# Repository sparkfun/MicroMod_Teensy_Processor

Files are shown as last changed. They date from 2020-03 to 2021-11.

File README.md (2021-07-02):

SparkFun MicroMod Teensy Processor Board 
========================================

SparkFun MicroMod Teensy Processor Board

[SparkFun MicroMod Teensy Processor Board](https://www.sparkfun.com/products/16402)

The SparkFun MicroMod Teensy Processor Board leverages the incredible computing power of the NXP iMXRT1062 chip and pairs it with the M.2 MicroMod connector to allow you to plug it into your choice of compatible SparkFun MicroMod Carrier Board.

Repository Contents
-------------------

* **/Documents** - Datasheets, schematic, etc.
* **/Hardware** - Eagle design files (.brd, .sch)

Documentation
--------------
* **[Hookup Guide](https://learn.sparkfun.com/tutorials/micromod-teensy-processor-hookup-guide)** - Basic hookup guide for the SparkFun MicroMod Teensy Processor Board
* **[MicroMod Info Page](https://www.sparkfun.com/micromod)** - MicroMod Information Page

Version History
---------------
* **[DEV-16402](https://www.sparkfun.com/products/16402)** - Initial release.

License Information
-------------------

This product is _**open source**_! 

Please review the LICENSE.md file for license information. 

If you have any questions or concerns on licensing, please contact technical support on our [SparkFun forums](https://forum.sparkfun.com/viewforum.php?f=152).

Distributed as-is; no warranty is given.

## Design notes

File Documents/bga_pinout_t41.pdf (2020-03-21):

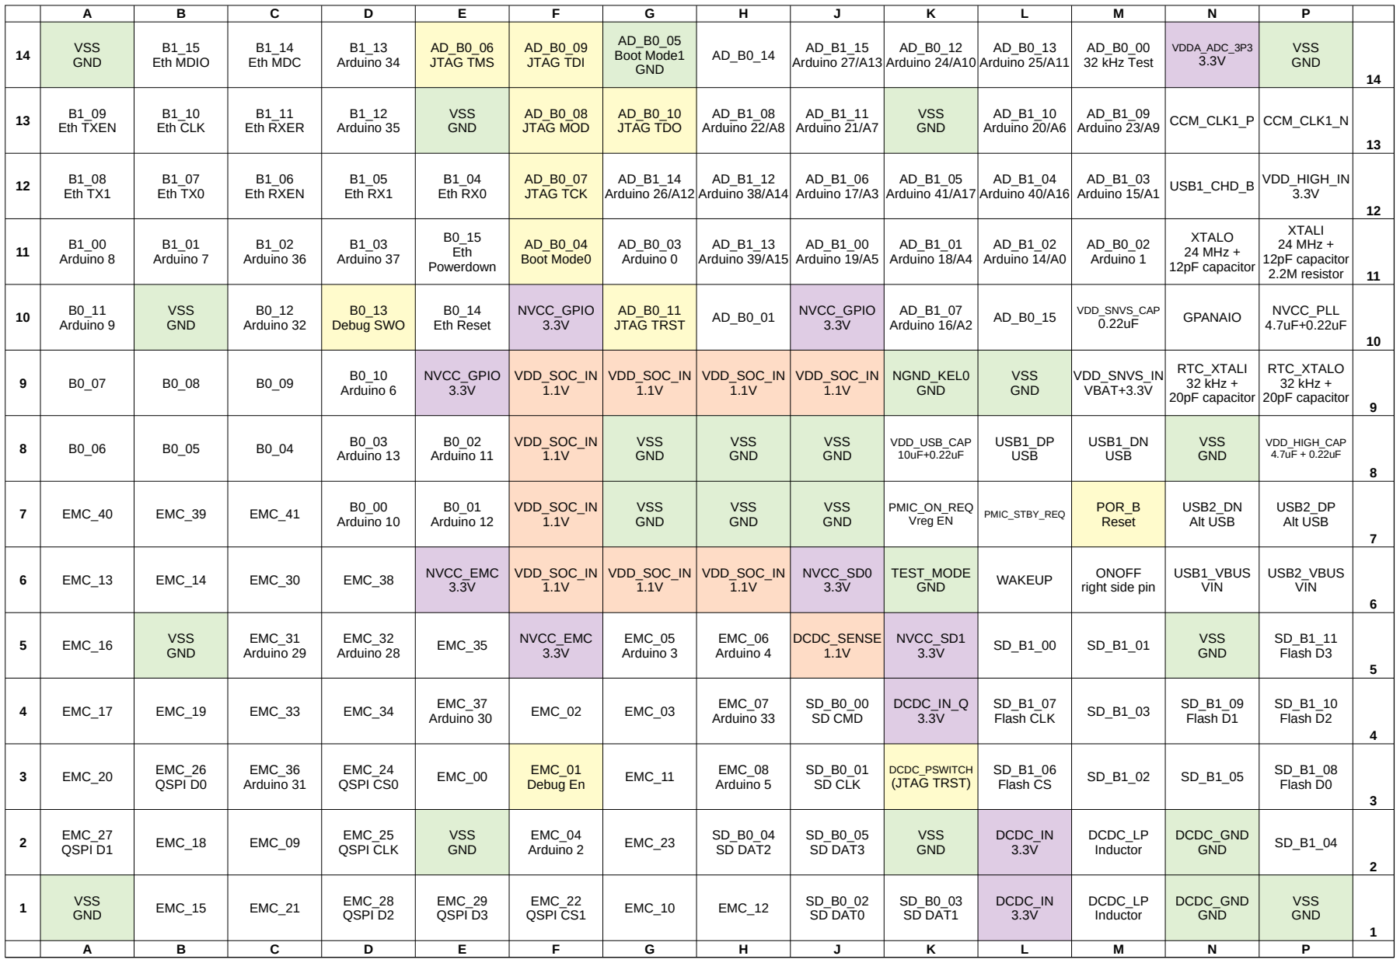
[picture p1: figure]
CCM_CLK1_P; CCM_CLK1_N; 12 USB1_CHD_B; GPANAIO; EMC_40; EMC_39; EMC_41; PMIC_STBY_REQ; EMC_13; EMC_14; EMC_30; EMC_38; WAKEUP; EMC_16; EMC_35; EMC_17; EMC_19; EMC_33; EMC_34; EMC_02; EMC_03; EMC_20; EMC_00; EMC_11; EMC_18; EMC_09; EMC_23; EMC_15; EMC_21; EMC_10; EMC_12; VSS GND; B1_15 Eth MDIO; B1_14 Eth MDC; B1_13 Arduino 34; AD_B0_06 JTAG TMS; AD_B0_09 JTAG TDI; AD_B0_05 Boot Mode1 GND; AD_B1_15 Arduino 27/A13; AD_B0_12 Arduino 24/A10; AD_B0_13 Arduino 25/A11; AD_B0_00 32 kHz Test; VDDA_ADC_3P3 3.3V; B1_09 Eth TXEN; B1_10 Eth CLK; B1_11 Eth RXER; B1_12 Arduino 35; AD_B0_08 JTAG MOD; AD_B0_10 JTAG TDO; AD_B1_08 Arduino 22/A8; AD_B1_11 Arduino 21/A7; AD_B1_10 Arduino 20/A6; AD_B1_09 Arduino 23/A9; B1_08 Eth TX1; B1_07 Eth TX0; B1_06 Eth RXEN; B1_05 Eth RX1; B1_04 Eth RX0; AD_B0_07 JTAG TCK; AD_B1_14 Arduino 26/A12; AD_B1_12 Arduino 38/A14; AD_B1_06 Arduino 17/A3; AD_B1_05 Arduino 41/A17; AD_B1_04 Arduino 40/A16; AD_B1_03 Arduino 15/A1; VDD_HIGH_IN 3.3V; B1_00 Arduino 8; B1_01 Arduino 7; B1_02 Arduino 36; B1_03 Arduino 37; B0_15 Eth Powerdown; AD_B0_04 Boot Mode0; AD_B0_03 Arduino 0; AD_B1_13 Arduino 39/A15; AD_B1_00 Arduino 19/A5; AD_B1_01 Arduino 18/A4; AD_B1_02 Arduino 14/A0; AD_B0_02 Arduino 1; XTALO 24 MHz + 12pF capacitor; XTALI 24 MHz + 12pF capacitor 2.2M resistor; B0_11 Arduino 9; B0_12 Arduino 32; B0_13 Debug SWO; B0_14 Eth Reset; NVCC_GPIO 3.3V; AD_B0_11 JTAG TRST; AD_B1_07 Arduino 16/A2; VDD_SNVS_CAP 0.22uF; NVCC_PLL 4.7uF+0.22uF; B0_10 Arduino 6; VDD_SOC_IN 1.1V; NGND_KEL0 GND; VDD_SNVS_IN VBAT+3.3V; RTC_XTALI 32 kHz + 20pF capacitor; RTC_XTALO 32 kHz + 20pF capacitor; B0_03 Arduino 13; B0_02 Arduino 11; VDD_USB_CAP 10uF+0.22uF; USB1_DP USB; USB1_DN USB; VDD_HIGH_CAP 4.7uF + 0.22uF; B0_00 Arduino 10; B0_01 Arduino 12; PMIC_ON_REQ Vreg EN; POR_B Reset; USB2_DN Alt USB; USB2_DP Alt USB; NVCC_EMC 3.3V; NVCC_SD0 3.3V; TEST_MODE GND; ONOFF right side pin; USB1_VBUS VIN; USB2_VBUS VIN; EMC_31 Arduino 29; EMC_32 Arduino 28; EMC_05 Arduino 3; EMC_06 Arduino 4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

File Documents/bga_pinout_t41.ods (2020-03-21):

 | A | B | C | D | E | F | G | H | J | K | L | M | N | P
14 | VSS GND | B1_15 Eth MDIO | B1_14 Eth MDC | B1_13 Arduino 34 | AD_B0_06 JTAG TMS | AD_B0_09 JTAG TDI | AD_B0_05 Boot Mode1 GND | AD_B0_14 | AD_B1_15 Arduino 27/A13 | AD_B0_12 Arduino 24/A10 | AD_B0_13 Arduino 25/A11 | AD_B0_00 32 kHz Test | VDDA_ADC_3P3 3.3V | VSS GND | 14
13 | B1_09 Eth TXEN | B1_10 Eth CLK | B1_11 Eth RXER | B1_12 Arduino 35 | VSS GND | AD_B0_08 JTAG MOD | AD_B0_10 JTAG TDO | AD_B1_08 Arduino 22/A8 | AD_B1_11 Arduino 21/A7 | VSS GND | AD_B1_10 Arduino 20/A6 | AD_B1_09 Arduino 23/A9 | CCM_CLK1_P | CCM_CLK1_N | 13
12 | B1_08 Eth TX1 | B1_07 Eth TX0 | B1_06 Eth RXEN | B1_05 Eth RX1 | B1_04 Eth RX0 | AD_B0_07 JTAG TCK | AD_B1_14 Arduino 26/A12 | AD_B1_12 Arduino 38/A14 | AD_B1_06 Arduino 17/A3 | AD_B1_05 Arduino 41/A17 | AD_B1_04 Arduino 40/A16 | AD_B1_03 Arduino 15/A1 | USB1_CHD_B | VDD_HIGH_IN 3.3V | 12
11 | B1_00 Arduino 8 | B1_01 Arduino 7 | B1_02 Arduino 36 | B1_03 Arduino 37 | B0_15 Eth Powerdown | AD_B0_04 Boot Mode0 | AD_B0_03 Arduino 0 | AD_B1_13 Arduino 39/A15 | AD_B1_00 Arduino 19/A5 | AD_B1_01 Arduino 18/A4 | AD_B1_02 Arduino 14/A0 | AD_B0_02 Arduino 1 | XTALO 24 MHz + 12pF capacitor | XTALI 24 MHz + 12pF capacitor 2.2M resistor | 11
10 | B0_11 Arduino 9 | VSS GND | B0_12 Arduino 32 | B0_13 Debug SWO | B0_14 Eth Reset | NVCC_GPIO 3.3V | AD_B0_11 JTAG TRST | AD_B0_01 | NVCC_GPIO 3.3V | AD_B1_07 Arduino 16/A2 | AD_B0_15 | VDD_SNVS_CAP 0.22uF | GPANAIO | NVCC_PLL 4.7uF+0.22uF | 10
9 | B0_07 | B0_08 | B0_09 | B0_10 Arduino 6 | NVCC_GPIO 3.3V | VDD_SOC_IN 1.1V | VDD_SOC_IN 1.1V | VDD_SOC_IN 1.1V | VDD_SOC_IN 1.1V | NGND_KEL0 GND | VSS GND | VDD_SNVS_IN VBAT+3.3V | RTC_XTALI 32 kHz + 20pF capacitor | RTC_XTALO 32 kHz + 20pF capacitor | 9
8 | B0_06 | B0_05 | B0_04 | B0_03 Arduino 13 | B0_02 Arduino 11 | VDD_SOC_IN 1.1V | VSS GND | VSS GND | VSS GND | VDD_USB_CAP 10uF+0.22uF | USB1_DP USB | USB1_DN USB | VSS GND | VDD_HIGH_CAP 4.7uF + 0.22uF | 8
7 | EMC_40 | EMC_39 | EMC_41 | B0_00 Arduino 10 | B0_01 Arduino 12 | VDD_SOC_IN 1.1V | VSS GND | VSS GND | VSS GND | PMIC_ON_REQ Vreg EN | PMIC_STBY_REQ | POR_B Reset | USB2_DN Alt USB | USB2_DP Alt USB | 7
6 | EMC_13 | EMC_14 | EMC_30 | EMC_38 | NVCC_EMC 3.3V | VDD_SOC_IN 1.1V | VDD_SOC_IN 1.1V | VDD_SOC_IN 1.1V | NVCC_SD0 3.3V | TEST_MODE GND | WAKEUP | ONOFF right side pin | USB1_VBUS VIN | USB2_VBUS VIN | 6
5 | EMC_16 | VSS GND | EMC_31 Arduino 29 | EMC_32 Arduino 28 | EMC_35 | NVCC_EMC 3.3V | EMC_05 Arduino 3 | EMC_06 Arduino 4 | DCDC_SENSE 1.1V | NVCC_SD1 3.3V | SD_B1_00 | SD_B1_01 | VSS GND | SD_B1_11 Flash D3 | 5
4 | EMC_17 | EMC_19 | EMC_33 | EMC_34 | EMC_37 Arduino 30 | EMC_02 | EMC_03 | EMC_07 Arduino 33 | SD_B0_00 SD CMD | DCDC_IN_Q 3.3V | SD_B1_07 Flash CLK | SD_B1_03 | SD_B1_09 Flash D1 | SD_B1_10 Flash D2 | 4
3 | EMC_20 | EMC_26 QSPI D0 | EMC_36 Arduino 31 | EMC_24 QSPI CS0 | EMC_00 | EMC_01 Debug En | EMC_11 | EMC_08 Arduino 5 | SD_B0_01 SD CLK | DCDC_PSWITCH (JTAG TRST) | SD_B1_06 Flash CS | SD_B1_02 | SD_B1_05 | SD_B1_08 Flash D0 | 3
2 | EMC_27 QSPI D1 | EMC_18 | EMC_09 | EMC_25 QSPI CLK | VSS GND | EMC_04 Arduino 2 | EMC_23 | SD_B0_04 SD DAT2 | SD_B0_05 SD DAT3 | VSS GND | DCDC_IN 3.3V | DCDC_LP Inductor | DCDC_GND GND | SD_B1_04 | 2
1 | VSS GND | EMC_15 | EMC_21 | EMC_28 QSPI D2 | EMC_29 QSPI D3 | EMC_22 QSPI CS1 | EMC_10 | EMC_12 | SD_B0_02 SD DAT0 | SD_B0_03 SD DAT1 | DCDC_IN 3.3V | DCDC_LP Inductor | DCDC_GND GND | VSS GND | 1
 | A | B | C | D | E | F | G | H | J | K | L | M | N | P

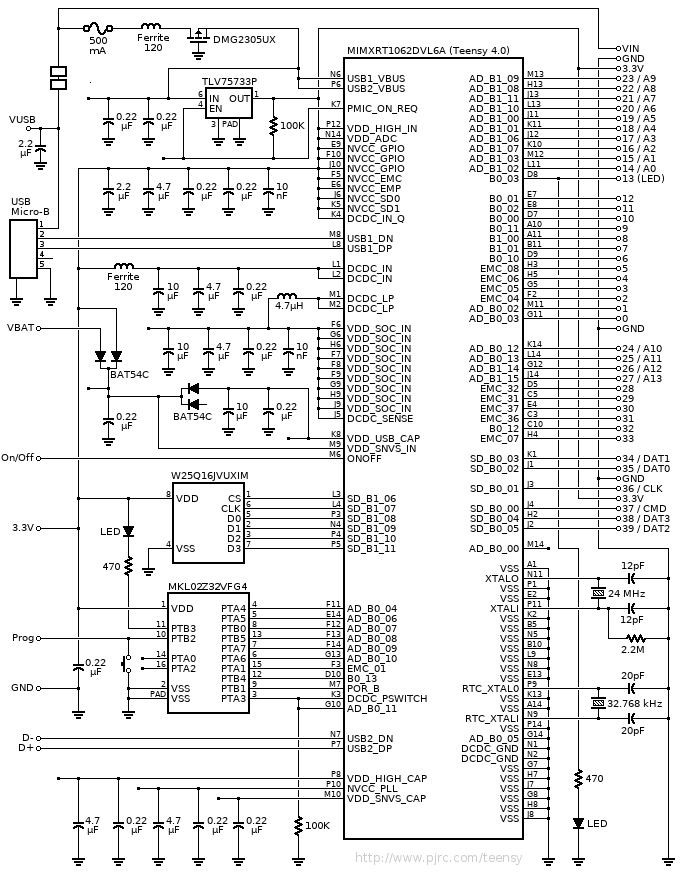
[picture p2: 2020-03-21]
Documents/schematic40.png

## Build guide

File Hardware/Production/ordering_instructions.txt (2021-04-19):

panel size, 189x70mm
PCB thickness, 0.8mm
number of layers, 4
soldermask color, Red
silkscreen color, White
oz copper, 1oz
finish, ENIG
stencils, none
pcs per panel, 16
min trace width, 0.1016mm / 0.0040in
min drill size, 0.2000mm / 0.0079in
filename to layer stackup 1/2/3/4: GTL, GL2, GL3, GBL
PCB requires 45 degree chamfer or bevel on edge

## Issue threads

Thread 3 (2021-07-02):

invalid URLs

mrccwolf, 2021-07-02:
Hookup Guide is 404
MicroMod Info Page is missing a "w" in "www"

Cool board!

nseidle, 2021-07-02:
Good catch. Fixed! Thanks

Closed 2021-07-02.

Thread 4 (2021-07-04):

Software support rtos

JPB1JPB1, 2021-07-04:
Dear Team

Great board but what about the software support with rtos low power USB Host wifi/bluetooth, sdio 4 bit mode , and all other features spi/i2c driver optimisation for speedy....
Azur or Thread X are running on it with ISO certification  ?
Which is the best ready to go on market rtos for it ?

Wiating for your hello and best regards
Jp

nseidle, 2021-07-07:
Thanks!

We wholly depend on the Teensy core for this product and do not plan to add separate RTOS support. That said, [there is quite a bit](https://www.google.com/search?q=teensy+rtos) of discussion and a few options currently available.

Closed 2021-07-07.

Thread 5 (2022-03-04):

MicroMod and Teensy 4/4.1 Pin Discrepancies

charliecarver, 2022-03-04:
I noticed a few discrepancies when matching the MicroMod pinout table to the Teensy 4 card from PJRC:

1. MicroMod pins 37 and 35 are both listed as USBHOST_D+

2. The G0…G4 MicroMod pins are listed as mapping to 40…44 on the Teensy (which aren’t in the Teensy 4 datasheet), and then later listed as:
	• G0 - GPIO pin 15, pad 40 on the MicroMod
	• G1 - GPIO pin 25, pad 42 on the MicroMod
	• G2 - GPIO pin 26, pad 44 on the MicroMod
	• G3 - GPIO pin 17, pad 46 on the MicroMod
	• G4 - GPIO pin 16, pad 48 on the MicroMod
	• G5 - GPIO pin 32, pad 73 on the MicroMod
	• G6 - GPIO pin 33, pad 71 on the MicroMod
However Teensy pins 15/25/26/etc… are already mapped to other pins?

nseidle, 2022-04-06:
Please link to sources where possible. I think you're talking about:

https://learn.sparkfun.com/tutorials/micromod-teensy-processor-hookup-guide/all#hardware-overview

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

See [schematic](https://cdn.sparkfun.com/assets/5/a/3/6/0/MicroMod-Teensy_V1_3.pdf)
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

Good catch, typo. Should be 37 = D-. Fixed now.

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

MicroMod Teensy exposes slightly more pins than the Teensy 4. We were *just* able to route to balls B0_04, B0_05, etc from the IMXRT1062DV, best visible in the schematic. These are called pin '40-45' in the Arduino world. These are electrically routed off the MM processor board on M.2 pins 40, 42, 44, 46, 48, 73. Sorry, it's confusing. Said differently, a `digitalWrite(45, HIGH)` should cause G5 (pin 73) on the MicroMod carrier board to go high.

I believe the "G0 - GPIO pin 15, pad 40 on the..." may have been a copy/paste typo. I'll have someone double check it.

Thanks for reporting!

nseidle, 2022-04-06:
Yep - copy paste error. Should be fixed now.

Closed 2022-04-06.

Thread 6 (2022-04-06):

PID/VID for Teensy Micromod

mjs513, 2022-04-06:
A forum post has been generated by @KurtE to assign a PID/VID for the Teensy Micromod board. Saw they were generated for other micromod boards but nothing so far for the Teensy.  Would like to add circuitpython to the board so this is needed.  Please either answer here or on the fourm.

nseidle, 2022-04-06:
Perhaps I'm confused but @PaulStoffregen assigns the VID/PID according to his HID bootloader and serial port driver. We don't have control over it.

From a quick look,

VID = 0x16C0
PID = 0x0478
PID = 0x0483 (Serial Port mode)

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

KurtE, 2022-04-06:
Note: I posted more information in the forum thread: https://forum.sparkfun.com/viewtopic.php?f=182&t=57464&p=232370#p232370

Closed 2022-04-06.

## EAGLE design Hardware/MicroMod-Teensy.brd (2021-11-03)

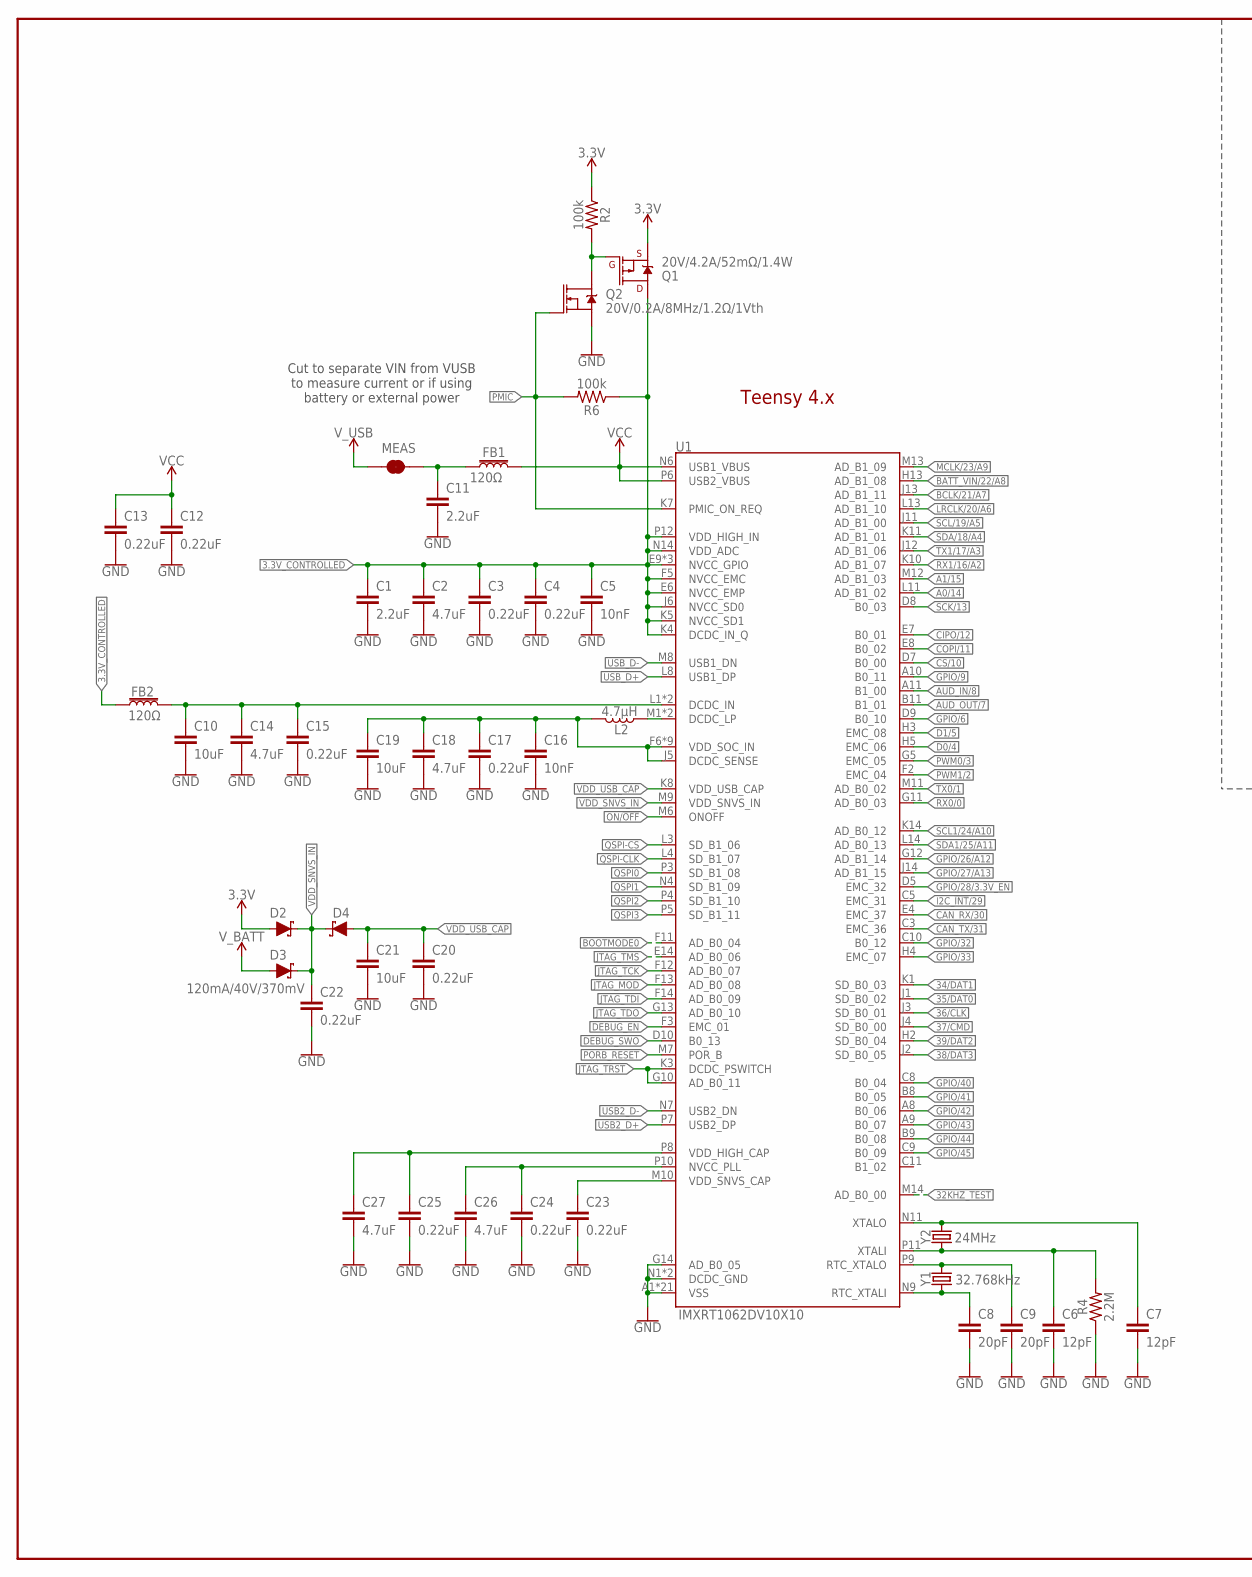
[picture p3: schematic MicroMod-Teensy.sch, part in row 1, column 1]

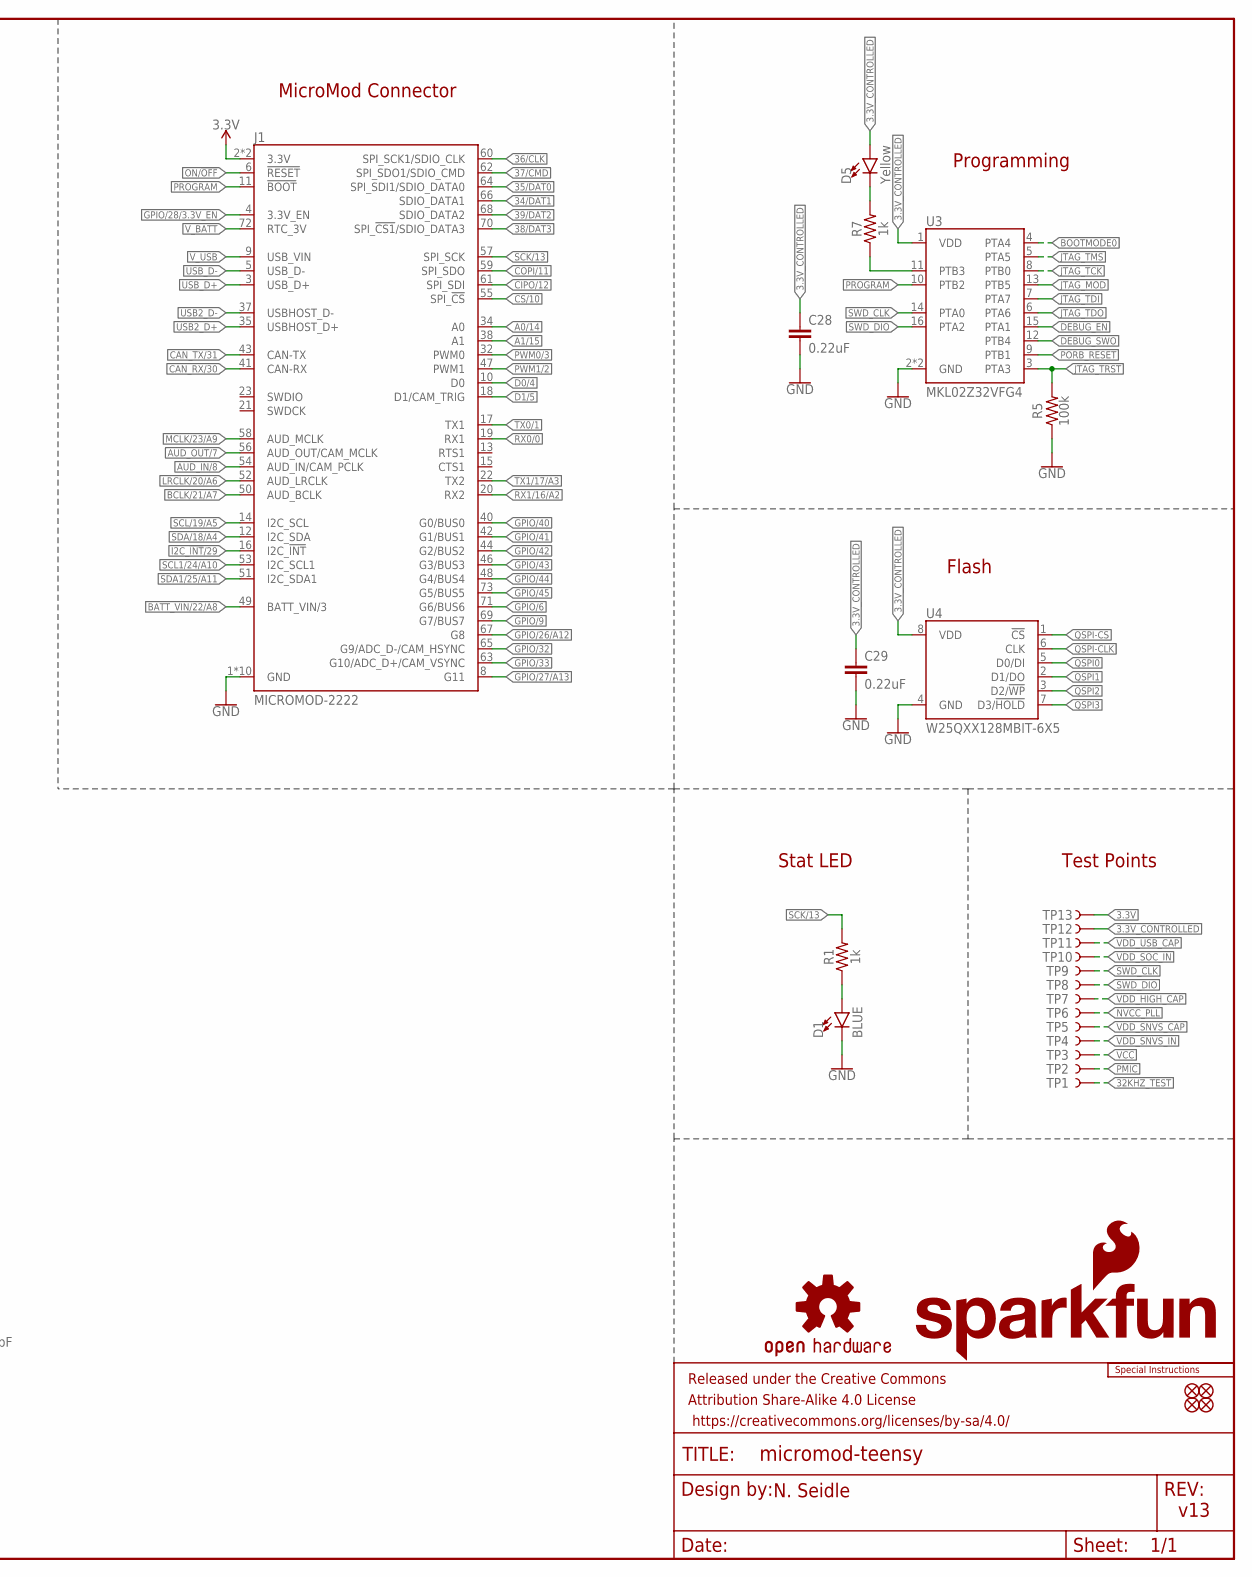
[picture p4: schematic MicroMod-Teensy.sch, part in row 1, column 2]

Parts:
C1, C11: 2.2uF; 0402-TIGHT
C2, C14, C18, C26, C27: 4.7uF; 0402-TIGHT
C3, C4, C12, C13, C15, C17, C20, C22, C23, C24, C25, C28, C29: 0.22uF; 0402-TIGHT
C5, C16: 10nF; 0402-TIGHT
C6, C7: 12pF; 0402-TIGHT
C8, C9: 20pF; 0402-TIGHT
C10, C19, C21: 10uF; 0402-TIGHT
D1: BLUE; LED-0603
D2, D3, D4: 120mA/40V/370mV; SOD-523
D5: Yellow; LED-0603
FB1, FB2: 120Ω; 0402-TIGHT
FD1, FD2, FD3, FD4: FIDUCIALUFIDUCIAL; FIDUCIAL-MICRO
FRAME1: FRAME-LEDGER; CREATIVE_COMMONS
J1: MICROMOD-2222; M.2-CARD-E-22
L2: 4.7μH; 1008(2520)
LOGO1: SFE_LOGO_NAME_FLAME.1_INCH; SFE_LOGO_NAME_FLAME_.1
LOGO2: OSHW-LOGONO_SILK; DUMMY
LOGO3: SPECIAL_INSTRUCTIONS-ORDERING; ORDERING_INSTRUCTIONS
MEAS: JUMPER-SMT_2_NC_TRACE_SILK; SMT-JUMPER_2_NC_TRACE_SILK
Q1: 20V/4.2A/52mΩ/1.4W; SOT23-3
Q2: 20V/0.2A/8MHz/1.2Ω/1Vth; SOT-416FL
R1, R7: 1k; 0402-TIGHT
R2, R5, R6: 100k; 0402-TIGHT
R4: 2.2M; 0402-TIGHT
TP1, TP2, TP3, TP4, TP5, TP6, TP7, TP8, TP9, TP10, TP11, TP12, TP13: TEST-POINT3; PAD.03X.03
U1: IMXRT1062DV10X10; IMXRT1062
U3: MKL02Z32VFG4; QFN-16
U4: W25QXX128MBIT-6X5; WSON-8-6X5-SKINNY_CENTERPAD
Y1: 32.768kHz; CRYSTAL-SMD-3.2X1.5MM
Y2: 24MHz; CRYSTAL-SMD-2.0X1.6MM

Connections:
3.3V: D2.A, J1.2 (3.3V), J1.74 (3.3V), Q1.2 (S), R2.1, TP13.P$1
3.3V_CONTROLLED: C1.1, C2.1, C3.1, C4.1, C5.1, C28.1, C29.1, D5.A, FB2.1, Q1.3 (D), R6.1, TP12.P$1, U1.E6 (NVCC_EMP), U1.E9 (NVCC_GPIO), U1.F5 (NVCC_EMC), U1.F10 (NVCC_GPIO), U1.J6 (NVCC_SD0), U1.J10 (NVCC_GPIO), U1.K4 (DCDC_IN_Q), U1.K5 (NVCC_SD1), U1.N14 (VDD_ADC), U1.P12 (VDD_HIGH_IN), U3.1 (VDD), U4.8 (VDD)
24MHZ_1: C7.1, U1.N11 (XTALO), Y2.3 (2)
24MHZ_2: C6.1, R4.2, U1.P11 (XTALI), Y2.1
32KHZ_1: C8.1, U1.N9 (RTC_XTALI), Y1.P$1 (1)
32KHZ_2: C9.1, U1.P9 (RTC_XTALO), Y1.P$2 (2)
32KHZ_TEST: TP1.P$1, U1.M14 (AD_B0_00)
34/DAT1: J1.66 (SDIO_DATA1), U1.K1 (SD_B0_03)
35/DAT0: J1.64 (SPI_SDI1/SDIO_DATA0), U1.J1 (SD_B0_02)
36/CLK: J1.60 (SPI_SCK1/SDIO_CLK), U1.J3 (SD_B0_01)
37/CMD: J1.62 (SPI_SDO1/SDIO_CMD), U1.J4 (SD_B0_00)
38/DAT3: J1.70 (SPI_!CS1!/SDIO_DATA3), U1.J2 (SD_B0_05)
39/DAT2: J1.68 (SDIO_DATA2), U1.H2 (SD_B0_04)
A0/14: J1.34 (A0), U1.L11 (AD_B1_02)
A1/15: J1.38 (A1), U1.M12 (AD_B1_03)
AUD_IN/8: J1.54 (AUD_IN/CAM_PCLK), U1.A11 (B1_00)
AUD_OUT/7: J1.56 (AUD_OUT/CAM_MCLK), U1.B11 (B1_01)
BATT_VIN/22/A8: J1.49 (BATT_VIN/3), U1.H13 (AD_B1_08)
BCLK/21/A7: J1.50 (AUD_BCLK), U1.J13 (AD_B1_11)
BOOTMODE0: U1.F11 (AD_B0_04), U3.4 (PTA4)
CAN_RX/30: J1.41 (CAN-RX), U1.E4 (EMC_37)
CAN_TX/31: J1.43 (CAN-TX), U1.C3 (EMC_36)
CIPO/12: J1.61 (SPI_SDI), U1.E7 (B0_01)
COPI/11: J1.59 (SPI_SDO), U1.E8 (B0_02)
CS/10: J1.55 (SPI_!CS!), U1.D7 (B0_00)
D0/4: J1.10 (D0), U1.H5 (EMC_06)
D1/5: J1.18 (D1/CAM_TRIG), U1.H3 (EMC_08)
DCDC_IN: C10.1, C14.1, C15.1, FB2.2, U1.L1 (DCDC_IN), U1.L2 (DCDC_IN)
DCDC_LP: L2.1, U1.M1 (DCDC_LP), U1.M2 (DCDC_LP)
DEBUG_EN: U1.F3 (EMC_01), U3.15 (PTA1)
DEBUG_SWO: U1.D10 (B0_13), U3.12 (PTB4)
GND: C1.2, C2.2, C3.2, C4.2, C5.2, C6.2, C7.2, C8.2, C9.2, C10.2, C11.2, C12.2, C13.2, C14.2, C15.2, C16.2, C17.2, C18.2, C19.2, C20.2, C21.2, C22.2, C23.2, C24.2, C25.2, C26.2, C27.2, C28.2, C29.2, D1.C, J1.1 (GND), J1.7 (GND), J1.33 (GND), J1.36 (GND), J1.39 (GND), J1.45 (GND), J1.75 (GND), J1.GND1 (GND), J1.GND2 (GND), J1.GND3 (GND), Q2.2 (S), R4.1, R5.1, U1.A1 (VSS), U1.A14 (VSS), U1.B5 (VSS), U1.B10 (VSS), U1.E2 (VSS), U1.E13 (VSS), U1.G7 (VSS), U1.G8 (VSS), U1.G14 (AD_B0_05), U1.H7 (VSS), U1.H8 (VSS), U1.J7 (VSS), U1.J8 (VSS), U1.K2 (VSS), U1.K6 (VSS), U1.K9 (VSS), U1.K13 (VSS), U1.L9 (VSS), U1.N1 (DCDC_GND), U1.N2 (DCDC_GND), U1.N5 (VSS), U1.N8 (VSS), U1.P1 (VSS), U1.P14 (VSS), U3.2 (GND), U3.17 (GND), U4.4 (GND)
GPIO/6: J1.71 (G6/BUS6), U1.D9 (B0_10)
GPIO/9: J1.69 (G7/BUS7), U1.A10 (B0_11)
GPIO/26/A12: J1.67 (G8), U1.G12 (AD_B1_14)
GPIO/27/A13: J1.8 (G11), U1.J14 (AD_B1_15)
GPIO/28/3.3V_EN: J1.4 (3.3V_EN), U1.D5 (EMC_32)
GPIO/32: J1.65 (G9/ADC_D-/CAM_HSYNC), U1.C10 (B0_12)
GPIO/33: J1.63 (G10/ADC_D+/CAM_VSYNC), U1.H4 (EMC_07)
GPIO/40: J1.40 (G0/BUS0), U1.C8 (B0_04)
GPIO/41: J1.42 (G1/BUS1), U1.B8 (B0_05)
GPIO/42: J1.44 (G2/BUS2), U1.A8 (B0_06)
GPIO/43: J1.46 (G3/BUS3), U1.A9 (B0_07)
GPIO/44: J1.48 (G4/BUS4), U1.B9 (B0_08)
GPIO/45: J1.73 (G5/BUS5), U1.C9 (B0_09)
I2C_!INT!/29: J1.16 (I2C_!INT!), U1.C5 (EMC_31)
JTAG_MOD: U1.F13 (AD_B0_08), U3.13 (PTB5)
JTAG_TCK: U1.F12 (AD_B0_07), U3.8 (PTB0)
JTAG_TDI: U1.F14 (AD_B0_09), U3.7 (PTA7)
JTAG_TDO: U1.G13 (AD_B0_10), U3.6 (PTA6)
JTAG_TMS: U1.E14 (AD_B0_06), U3.5 (PTA5)
JTAG_TRST: R5.2, U1.G10 (AD_B0_11), U1.K3 (DCDC_PSWITCH), U3.3 (PTA3)
LRCLK/20/A6: J1.52 (AUD_LRCLK), U1.L13 (AD_B1_10)
MCLK/23/A9: J1.58 (AUD_MCLK), U1.M13 (AD_B1_09)
unnamed: D1.A, R1.1
unnamed: Q1.1 (G), Q2.3 (D), R2.2
unnamed: C11.1, FB1.1, MEAS.2
unnamed: R7.1, U3.11 (PTB3)
unnamed: D5.C, R7.2
NVCC_PLL: C24.1, C26.1, TP6.P$1, U1.P10 (NVCC_PLL)
ON/!OFF!: J1.6 (!RESET!), U1.M6 (ONOFF)
PMIC: Q2.1 (G), R6.2, TP2.P$1, U1.K7 (PMIC_ON_REQ)
PORB_RESET: U1.M7 (POR_B), U3.9 (PTB1)
PROGRAM: J1.11 (!BOOT!), U3.10 (PTB2)
PWM0/3: J1.32 (PWM0), U1.G5 (EMC_05)
PWM1/2: J1.47 (PWM1), U1.F2 (EMC_04)
QSPI0: U1.P3 (SD_B1_08), U4.5 (D0/DI)
QSPI1: U1.N4 (SD_B1_09), U4.2 (D1/DO)
QSPI2: U1.P4 (SD_B1_10), U4.3 (D2/!WP!)
QSPI3: U1.P5 (SD_B1_11), U4.7 (D3/!HOLD!)
QSPI-CLK: U1.L4 (SD_B1_07), U4.6 (CLK)
QSPI-CS: U1.L3 (SD_B1_06), U4.1 (!CS!)
RX0/0: J1.19 (RX1), U1.G11 (AD_B0_03)
RX1/16/A2: J1.20 (RX2), U1.K10 (AD_B1_07)
SCK/13: J1.57 (SPI_SCK), R1.2, U1.D8 (B0_03)
SCL1/24/A10: J1.53 (I2C_SCL1), U1.K14 (AD_B0_12)
SCL/19/A5: J1.14 (I2C_SCL), U1.J11 (AD_B1_00)
SDA1/25/A11: J1.51 (I2C_SDA1), U1.L14 (AD_B0_13)
SDA/18/A4: J1.12 (I2C_SDA), U1.K11 (AD_B1_01)
SWD_CLK: TP9.P$1, U3.14 (PTA0)
SWD_DIO: TP8.P$1, U3.16 (PTA2)
TX0/1: J1.17 (TX1), U1.M11 (AD_B0_02)
TX1/17/A3: J1.22 (TX2), U1.J12 (AD_B1_06)
USB2_D+: J1.35 (USBHOST_D+), U1.P7 (USB2_DP)
USB2_D-: J1.37 (USBHOST_D-), U1.N7 (USB2_DN)
USB_D+: J1.3 (USB_D+), U1.L8 (USB1_DP)
USB_D-: J1.5 (USB_D-), U1.M8 (USB1_DN)
VCC: C12.1, C13.1, FB1.2, TP3.P$1, U1.N6 (USB1_VBUS), U1.P6 (USB2_VBUS)
VDD_HIGH_CAP: C25.1, C27.1, TP7.P$1, U1.P8 (VDD_HIGH_CAP)
VDD_SNVS_CAP: C23.1, TP5.P$1, U1.M10 (VDD_SNVS_CAP)
VDD_SNVS_IN: C22.1, D2.C, D3.C, D4.C, TP4.P$1, U1.M9 (VDD_SNVS_IN)
VDD_SOC_IN: C16.1, C17.1, C18.1, C19.1, L2.2, TP10.P$1, U1.F6 (VDD_SOC_IN), U1.F7 (VDD_SOC_IN), U1.F8 (VDD_SOC_IN), U1.F9 (VDD_SOC_IN), U1.G6 (VDD_SOC_IN), U1.G9 (VDD_SOC_IN), U1.H6 (VDD_SOC_IN), U1.H9 (VDD_SOC_IN), U1.J5 (DCDC_SENSE), U1.J9 (VDD_SOC_IN)
VDD_USB_CAP: C20.1, C21.1, D4.A, TP11.P$1, U1.K8 (VDD_USB_CAP)
V_BATT: D3.A, J1.72 (RTC_3V)
V_USB: J1.9 (USB_VIN), MEAS.1

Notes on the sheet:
v13
N. Seidle
MicroMod Connector
Teensy 4.x
Flash
Stat LED
Programming
Cut to separate VIN from VUSB to measure current or if using battery or external power
Test Points

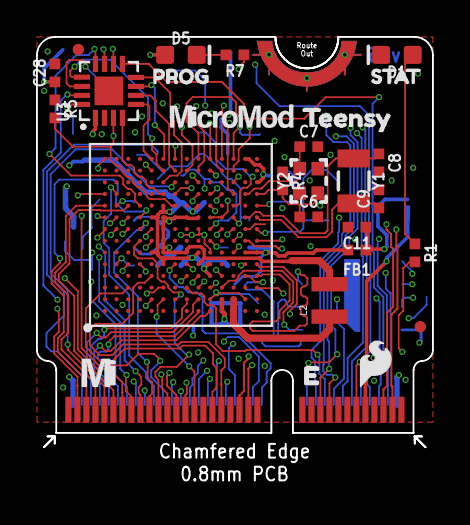
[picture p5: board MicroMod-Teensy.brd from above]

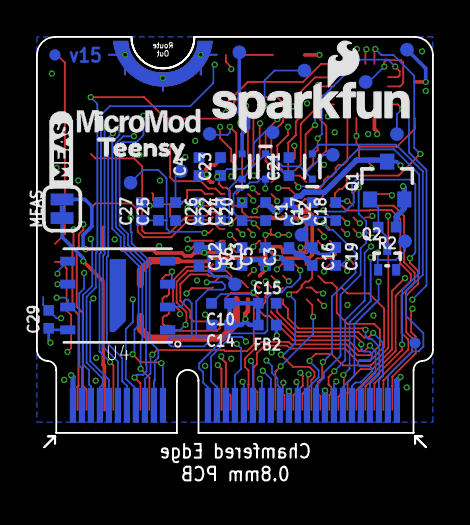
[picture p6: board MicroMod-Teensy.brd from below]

Board: 4 copper layers, 22.0 x 22.8 mm, 82 parts (52 on the bottom side), 95 nets.

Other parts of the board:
U$1, U$3: TEENSY2
U$4: MICROMOD_MI_LOGO_.35
U$6: SFE_LOGO_FLAME_.1
U$7, U$11: MICROMOD_LOGO_.3
U$8: MEAS2
U$9: PROG0
U$10: STAT1

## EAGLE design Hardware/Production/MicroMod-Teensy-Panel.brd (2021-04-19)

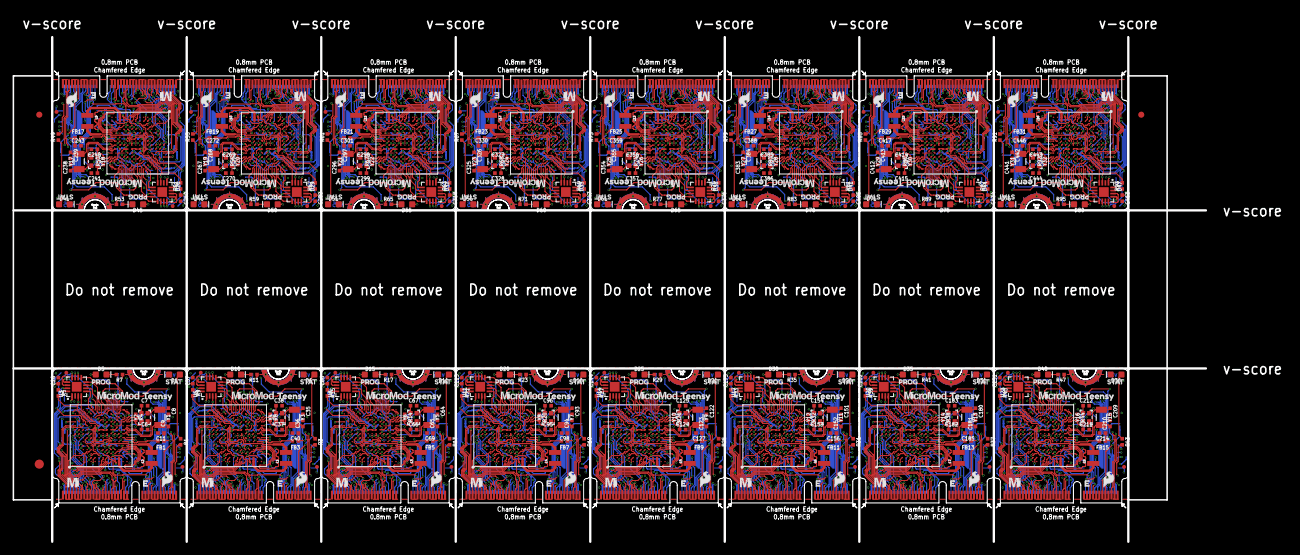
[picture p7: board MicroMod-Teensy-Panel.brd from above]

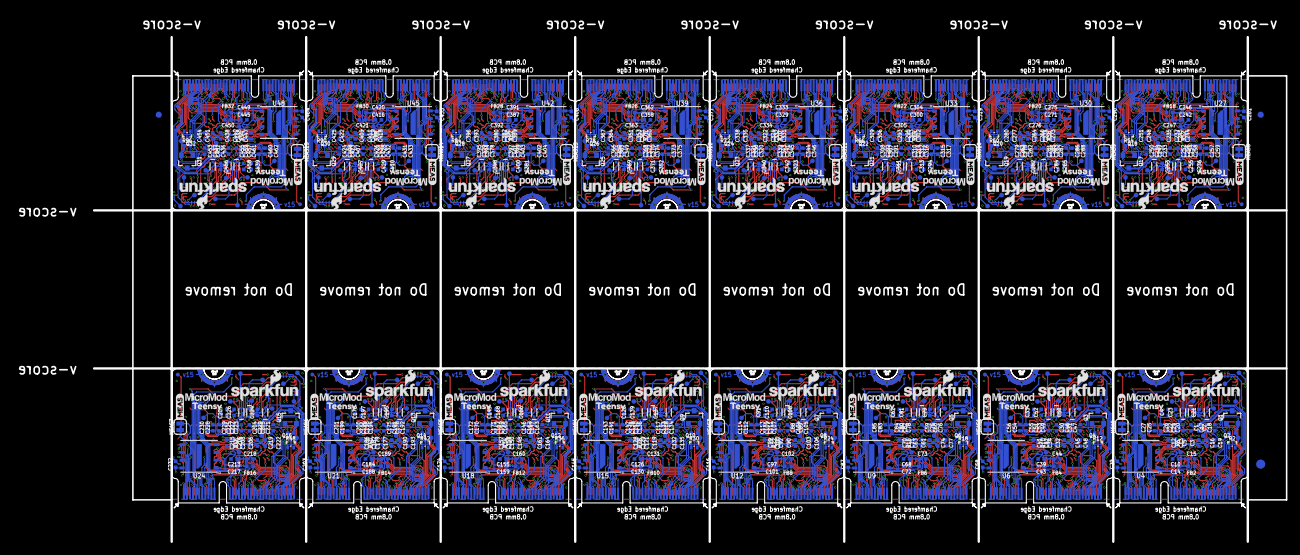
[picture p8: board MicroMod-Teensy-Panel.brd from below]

Board: 4 copper layers, 195.0 x 82.5 mm, 1270 parts (835 on the bottom side), 1520 nets.

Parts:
C1, C11, C30, C40, C59, C69, C88, C98, C117, C127, C146, C156, C175, C185, C204, C214, C233, C243, C262, C272, C291, C301, C320, C330, C349, C359, C378, C388, C407, C417, C436, C446: 2.2uF; 0402-TIGHT
C2, C14, C18, C26, C27, C31, C43, C47, C55, C56, C60, C72, C76, C84, C85, C89, C101, C105, C113, C114, C118, C130, C134, C142, C143, C147, C159, C163, C171, C172, C176, C188, C192, C200, C201, C205, C217, C221, C229, C230, C234, C246, C250, C258, C259, C263, C275, C279, C287, C288, C292, C304, C308, C316, C317, C321, C333, C337, C345, C346, C350, C362, C366, C374, C375, C379, C391, C395, C403, C404, C408, C420, C424, C432, C433, C437, C449, C453, C461, C462: 4.7uF; 0402-TIGHT
C3, C4, C12, C13, C15, C17, C20, C22, C23, C24, C25, C28, C29, C32, C33, C41, C42, C44, C46, C49, C51, C52, C53, C54, C57, C58, C61, C62, C70, C71, C73, C75, C78, C80, C81, C82, C83, C86, C87, C90, C91, C99, C100, C102, C104, C107, C109, C110, C111, C112, C115, C116, C119, C120, C128, C129, C131, C133, C136, C138, C139, C140, C141, C144, C145, C148, C149, C157, C158, C160, C162, C165, C167, C168, C169, C170, C173, C174, C177, C178, C186, C187, C189, C191, C194, C196, C197, C198, C199, C202, C203, C206, C207, C215, C216, C218, C220, C223, C225, C226, C227, C228, C231, C232, C235, C236, C244, C245, C247, C249, C252, C254, C255, C256, C257, C260, C261, C264, C265, C273, C274, C276, C278, C281, C283, C284, C285, C286, C289, C290, C293, C294, C302, C303, C305, C307, C310, C312, C313, C314, C315, C318, C319, C322, C323, C331, C332, C334, C336, C339, C341, C342, C343, C344, C347, C348, C351, C352, C360, C361, C363, C365, C368, C370, C371, C372, C373, C376, C377, C380, C381, C389, C390, C392, C394, C397, C399, C400, C401, C402, C405, C406, C409, C410, C418, C419, C421, C423, C426, C428, C429, C430, C431, C434, C435, C438, C439, C447, C448, C450, C452, C455, C457, C458, C459, C460, C463, C464: 0.22uF; 0402-TIGHT
C5, C16, C34, C45, C63, C74, C92, C103, C121, C132, C150, C161, C179, C190, C208, C219, C237, C248, C266, C277, C295, C306, C324, C335, C353, C364, C382, C393, C411, C422, C440, C451: 10nF; 0402-TIGHT
C6, C7, C37, C38, C66, C67, C95, C96, C124, C125, C153, C154, C182, C183, C211, C212, C240, C241, C269, C270, C298, C299, C327, C328, C356, C357, C385, C386, C414, C415, C443, C444: 12pF; 0402-TIGHT
C8, C9, C35, C36, C64, C65, C93, C94, C122, C123, C151, C152, C180, C181, C209, C210, C238, C239, C267, C268, C296, C297, C325, C326, C354, C355, C383, C384, C412, C413, C441, C442: 20pF; 0402-TIGHT
C10, C19, C21, C39, C48, C50, C68, C77, C79, C97, C106, C108, C126, C135, C137, C155, C164, C166, C184, C193, C195, C213, C222, C224, C242, C251, C253, C271, C280, C282, C300, C309, C311, C329, C338, C340, C358, C367, C369, C387, C396, C398, C416, C425, C427, C445, C454, C456: 10uF; 0402-TIGHT
D1, D6, D11, D16, D21, D26, D31, D36, D41, D46, D51, D56, D61, D66, D71, D76: BLUE; LED-0603
D2, D3, D4, D7, D8, D9, D12, D13, D14, D17, D18, D19, D22, D23, D24, D27, D28, D29, D32, D33, D34, D37, D38, D39, D42, D43, D44, D47, D48, D49, D52, D53, D54, D57, D58, D59, D62, D63, D64, D67, D68, D69, D72, D73, D74, D77, D78, D79: 120mA/40V/370mV; SOD-523
D5, D10, D15, D20, D25, D30, D35, D40, D45, D50, D55, D60, D65, D70, D75, D80: Yellow; LED-0603
E$1, E$2, E$3, E$4: FIDUCIAL-1X2
E$5, E$6: FIDUCIAL-1.5X3
FB1, FB2, FB3, FB4, FB5, FB6, FB7, FB8, FB9, FB10, FB11, FB12, FB13, FB14, FB15, FB16, FB17, FB18, FB19, FB20, FB21, FB22, FB23, FB24, FB25, FB26, FB27, FB28, FB29, FB30, FB31, FB32: 120Ω; 0402-TIGHT
FD1, FD2, FD3, FD4, FD5, FD6, FD7, FD8, FD9, FD10, FD11, FD12, FD13, FD14, FD15, FD16, FD17, FD18, FD19, FD20, FD21, FD22, FD23, FD24, FD25, FD26, FD27, FD28, FD29, FD30, FD31, FD32, FD33, FD34, FD35, FD36, FD37, FD38, FD39, FD40, FD41, FD42, FD43, FD44, FD45, FD46, FD47, FD48, FD49, FD50, FD51, FD52, FD53, FD54, FD55, FD56, FD57, FD58, FD59, FD60, FD61, FD62, FD63, FD64: FIDUCIALUFIDUCIAL; FIDUCIAL-MICRO
J1, J2, J3, J4, J5, J6, J7, J8, J9, J10, J11, J12, J13, J14, J15, J16: MICROMOD-2222; M.2-CARD-E-22
L1, L2, L3, L4, L5, L6, L7, L8, L9, L10, L11, L12, L13, L14, L15, L16: 4.7μH; 1008(2520)
LOGO1, LOGO2, LOGO3, LOGO4, LOGO5, LOGO6, LOGO7, LOGO8, LOGO9, LOGO10, LOGO11, LOGO12, LOGO13, LOGO14, LOGO15, LOGO16: SFE_LOGO_NAME_FLAME.1_INCH; SFE_LOGO_NAME_FLAME_.1
MEAS, MEAS1, MEAS2, MEAS3, MEAS4, MEAS5, MEAS6, MEAS7, MEAS8, MEAS9, MEAS10, MEAS11, MEAS12, MEAS13, MEAS14, MEAS15: SMT-JUMPER_2_NC_TRACE_SILK
Q1, Q3, Q5, Q7, Q9, Q11, Q13, Q15, Q17, Q19, Q21, Q23, Q25, Q27, Q29, Q31: 20V/4.2A/52mΩ/1.4W; SOT23-3
Q2, Q4, Q6, Q8, Q10, Q12, Q14, Q16, Q18, Q20, Q22, Q24, Q26, Q28, Q30, Q32: 20V/0.2A/8MHz/1.2Ω/1Vth; SOT-416FL
R1, R3, R7, R11, R13, R17, R19, R23, R25, R29, R31, R35, R37, R41, R43, R47, R49, R53, R55, R59, R61, R65, R67, R71, R73, R77, R79, R83, R85, R89, R91, R95: 1k; 0402-TIGHT
R2, R5, R6, R9, R10, R12, R15, R16, R18, R21, R22, R24, R27, R28, R30, R33, R34, R36, R39, R40, R42, R45, R46, R48, R51, R52, R54, R57, R58, R60, R63, R64, R66, R69, R70, R72, R75, R76, R78, R81, R82, R84, R87, R88, R90, R93, R94, R96: 100k; 0402-TIGHT
R4, R8, R14, R20, R26, R32, R38, R44, R50, R56, R62, R68, R74, R80, R86, R92: 2.2M; 0402-TIGHT
TP1, TP2, TP3, TP4, TP5, TP6, TP7, TP8, TP9, TP10, TP11, TP12, TP13, TP14, TP15, TP16, TP17, TP18, TP19, TP20, TP21, TP22, TP23, TP24, TP25, TP26, TP27, TP28, TP29, TP30, TP31, TP32, TP33, TP34, TP35, TP36, TP37, TP38, TP39, TP40, TP41, TP42, TP43, TP44, TP45, TP46, TP47, TP48, TP49, TP50, TP51, TP52, TP53, TP54, TP55, TP56, TP57, TP58, TP59, TP60, TP61, TP62, TP63, TP64, TP65, TP66, TP67, TP68, TP69, TP70, TP71, TP72, TP73, TP74, TP75, TP76, TP77, TP78, TP79, TP80, TP81, TP82, TP83, TP84, TP85, TP86, TP87, TP88, TP89, TP90, TP91, TP92, TP93, TP94, TP95, TP96, TP97, TP98, TP99, TP100, TP101, TP102, TP103, TP104, TP105, TP106, TP107, TP108, TP109, TP110, TP111, TP112, TP113, TP114, TP115, TP116, TP117, TP118, TP119, TP120, TP121, TP122, TP123, TP124, TP125, TP126, TP127, TP128, TP129, TP130, TP131, TP132, TP133, TP134, TP135, TP136, TP137, TP138, TP139, TP140, TP141, TP142, TP143, TP144, TP145, TP146, TP147, TP148, TP149, TP150, TP151, TP152, TP153, TP154, TP155, TP156, TP157, TP158, TP159, TP160, TP161, TP162, TP163, TP164, TP165, TP166, TP167, TP168, TP169, TP170, TP171, TP172, TP173, TP174, TP175, TP176, TP177, TP178, TP179, TP180, TP181, TP182, TP183, TP184, TP185, TP186, TP187, TP188, TP189, TP190, TP191, TP192, TP193, TP194, TP195, TP196, TP197, TP198, TP199, TP200, TP201, TP202, TP203, TP204, TP205, TP206, TP207, TP208: PAD.03X.03
U1, U2, U7, U10, U13, U16, U19, U22, U25, U28, U31, U34, U37, U40, U43, U46: IMXRT1062DV10X10; IMXRT1062
U3, U5, U8, U11, U14, U17, U20, U23, U26, U29, U32, U35, U38, U41, U44, U47: MKL02Z32VFG4; QFN-16
U4, U6, U9, U12, U15, U18, U21, U24, U27, U30, U33, U36, U39, U42, U45, U48: W25QXX128MBIT-6X5; WSON-8-6X5-SKINNY_CENTERPAD
U$1, U$2, U$3, U$5, U$19, U$20, U$28, U$29, U$37, U$38, U$46, U$47, U$55, U$56, U$64, U$65, U$73, U$74, U$82, U$83, U$91, U$92, U$100, U$101, U$109, U$110, U$118, U$119, U$127, U$128, U$136, U$137: TEENSY2
U$4, U$15, U$24, U$33, U$42, U$51, U$60, U$69, U$78, U$87, U$96, U$105, U$114, U$123, U$132, U$141: MICROMOD_MI_LOGO_.35
U$6, U$16, U$25, U$34, U$43, U$52, U$61, U$70, U$79, U$88, U$97, U$106, U$115, U$124, U$133, U$142: SFE_LOGO_FLAME_.1
U$7, U$11, U$17, U$18, U$26, U$27, U$35, U$36, U$44, U$45, U$53, U$54, U$62, U$63, U$71, U$72, U$80, U$81, U$89, U$90, U$98, U$99, U$107, U$108, U$116, U$117, U$125, U$126, U$134, U$135, U$143, U$144: MICROMOD_LOGO_.3
U$8, U$12, U$21, U$30, U$39, U$48, U$57, U$66, U$75, U$84, U$93, U$102, U$111, U$120, U$129, U$138: MEAS2
U$9, U$13, U$22, U$31, U$40, U$49, U$58, U$67, U$76, U$85, U$94, U$103, U$112, U$121, U$130, U$139: PROG0
U$10, U$14, U$23, U$32, U$41, U$50, U$59, U$68, U$77, U$86, U$95, U$104, U$113, U$122, U$131, U$140: STAT1
Y1, Y3, Y5, Y7, Y9, Y11, Y13, Y15, Y17, Y19, Y21, Y23, Y25, Y27, Y29, Y31: 32.768kHz; CRYSTAL-SMD-3.2X1.5MM
Y2, Y4, Y6, Y8, Y10, Y12, Y14, Y16, Y18, Y20, Y22, Y24, Y26, Y28, Y30, Y32: 24MHz; CRYSTAL-SMD-2.0X1.6MM

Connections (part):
3.3V: D2.A, J1.2, J1.74, Q1.2, R2.1, TP13.P$1
3.3V1: D7.A, J2.2, J2.74, Q3.2, R12.1, TP26.P$1
3.3V2: D12.A, J3.2, J3.74, Q5.2, R18.1, TP39.P$1
3.3V3: D17.A, J4.2, J4.74, Q7.2, R24.1, TP52.P$1
3.3V4: D22.A, J5.2, J5.74, Q9.2, R30.1, TP65.P$1
3.3V5: D27.A, J6.2, J6.74, Q11.2, R36.1, TP78.P$1
3.3V6: D32.A, J7.2, J7.74, Q13.2, R42.1, TP91.P$1
3.3V7: D37.A, J8.2, J8.74, Q15.2, R48.1, TP104.P$1
3.3V8: D42.A, J9.2, J9.74, Q17.2, R54.1, TP117.P$1
3.3V9: D47.A, J10.2, J10.74, Q19.2, R60.1, TP130.P$1
3.3V10: D52.A, J11.2, J11.74, Q21.2, R66.1, TP143.P$1
3.3V11: D57.A, J12.2, J12.74, Q23.2, R72.1, TP156.P$1
3.3V12: D62.A, J13.2, J13.74, Q25.2, R78.1, TP169.P$1
3.3V13: D67.A, J14.2, J14.74, Q27.2, R84.1, TP182.P$1
3.3V14: D72.A, J15.2, J15.74, Q29.2, R90.1, TP195.P$1
3.3V15: D77.A, J16.2, J16.74, Q31.2, R96.1, TP208.P$1
3.3V_CONTROLLED: C1.1, C2.1, C3.1, C4.1, C5.1, C28.1, C29.1, D5.A, FB2.1, Q1.3, R6.1, TP12.P$1, U1.E6, U1.E9, U1.F5, U1.F10, U1.J6, U1.J10, U1.K4, U1.K5, U1.N14, U1.P12, U3.1, U4.8
3.3V_CONTROLLED1: C30.1, C31.1, C32.1, C33.1, C34.1, C57.1, C58.1, D10.A, FB4.1, Q3.3, R10.1, TP25.P$1, U2.E6, U2.E9, U2.F5, U2.F10, U2.J6, U2.J10, U2.K4, U2.K5, U2.N14, U2.P12, U5.1, U6.8
3.3V_CONTROLLED2: C59.1, C60.1, C61.1, C62.1, C63.1, C86.1, C87.1, D15.A, FB6.1, Q5.3, R16.1, TP38.P$1, U7.E6, U7.E9, U7.F5, U7.F10, U7.J6, U7.J10, U7.K4, U7.K5, U7.N14, U7.P12, U8.1, U9.8
3.3V_CONTROLLED3: C88.1, C89.1, C90.1, C91.1, C92.1, C115.1, C116.1, D20.A, FB8.1, Q7.3, R22.1, TP51.P$1, U10.E6, U10.E9, U10.F5, U10.F10, U10.J6, U10.J10, U10.K4, U10.K5, U10.N14, U10.P12, U11.1, U12.8
3.3V_CONTROLLED4: C117.1, C118.1, C119.1, C120.1, C121.1, C144.1, C145.1, D25.A, FB10.1, Q9.3, R28.1, TP64.P$1, U13.E6, U13.E9, U13.F5, U13.F10, U13.J6, U13.J10, U13.K4, U13.K5, U13.N14, U13.P12, U14.1, U15.8
3.3V_CONTROLLED5: C146.1, C147.1, C148.1, C149.1, C150.1, C173.1, C174.1, D30.A, FB12.1, Q11.3, R34.1, TP77.P$1, U16.E6, U16.E9, U16.F5, U16.F10, U16.J6, U16.J10, U16.K4, U16.K5, U16.N14, U16.P12, U17.1, U18.8
3.3V_CONTROLLED6: C175.1, C176.1, C177.1, C178.1, C179.1, C202.1, C203.1, D35.A, FB14.1, Q13.3, R40.1, TP90.P$1, U19.E6, U19.E9, U19.F5, U19.F10, U19.J6, U19.J10, U19.K4, U19.K5, U19.N14, U19.P12, U20.1, U21.8
3.3V_CONTROLLED7: C204.1, C205.1, C206.1, C207.1, C208.1, C231.1, C232.1, D40.A, FB16.1, Q15.3, R46.1, TP103.P$1, U22.E6, U22.E9, U22.F5, U22.F10, U22.J6, U22.J10, U22.K4, U22.K5, U22.N14, U22.P12, U23.1, U24.8
3.3V_CONTROLLED8: C233.1, C234.1, C235.1, C236.1, C237.1, C260.1, C261.1, D45.A, FB18.1, Q17.3, R52.1, TP116.P$1, U25.E6, U25.E9, U25.F5, U25.F10, U25.J6, U25.J10, U25.K4, U25.K5, U25.N14, U25.P12, U26.1, U27.8
3.3V_CONTROLLED9: C262.1, C263.1, C264.1, C265.1, C266.1, C289.1, C290.1, D50.A, FB20.1, Q19.3, R58.1, TP129.P$1, U28.E6, U28.E9, U28.F5, U28.F10, U28.J6, U28.J10, U28.K4, U28.K5, U28.N14, U28.P12, U29.1, U30.8
3.3V_CONTROLLED10: C291.1, C292.1, C293.1, C294.1, C295.1, C318.1, C319.1, D55.A, FB22.1, Q21.3, R64.1, TP142.P$1, U31.E6, U31.E9, U31.F5, U31.F10, U31.J6, U31.J10, U31.K4, U31.K5, U31.N14, U31.P12, U32.1, U33.8
3.3V_CONTROLLED11: C320.1, C321.1, C322.1, C323.1, C324.1, C347.1, C348.1, D60.A, FB24.1, Q23.3, R70.1, TP155.P$1, U34.E6, U34.E9, U34.F5, U34.F10, U34.J6, U34.J10, U34.K4, U34.K5, U34.N14, U34.P12, U35.1, U36.8
3.3V_CONTROLLED12: C349.1, C350.1, C351.1, C352.1, C353.1, C376.1, C377.1, D65.A, FB26.1, Q25.3, R76.1, TP168.P$1, U37.E6, U37.E9, U37.F5, U37.F10, U37.J6, U37.J10, U37.K4, U37.K5, U37.N14, U37.P12, U38.1, U39.8
3.3V_CONTROLLED13: C378.1, C379.1, C380.1, C381.1, C382.1, C405.1, C406.1, D70.A, FB28.1, Q27.3, R82.1, TP181.P$1, U40.E6, U40.E9, U40.F5, U40.F10, U40.J6, U40.J10, U40.K4, U40.K5, U40.N14, U40.P12, U41.1, U42.8
3.3V_CONTROLLED14: C407.1, C408.1, C409.1, C410.1, C411.1, C434.1, C435.1, D75.A, FB30.1, Q29.3, R88.1, TP194.P$1, U43.E6, U43.E9, U43.F5, U43.F10, U43.J6, U43.J10, U43.K4, U43.K5, U43.N14, U43.P12, U44.1, U45.8
3.3V_CONTROLLED15: C436.1, C437.1, C438.1, C439.1, C440.1, C463.1, C464.1, D80.A, FB32.1, Q31.3, R94.1, TP207.P$1, U46.E6, U46.E9, U46.F5, U46.F10, U46.J6, U46.J10, U46.K4, U46.K5, U46.N14, U46.P12, U47.1, U48.8
24MHZ_1: C7.1, U1.N11, Y2.3
24MHZ_2: C6.1, R4.2, U1.P11, Y2.1
24MHZ_3: C38.1, U2.N11, Y4.3
24MHZ_4: C37.1, R8.2, U2.P11, Y4.1
24MHZ_5: C67.1, U7.N11, Y6.3
24MHZ_6: C66.1, R14.2, U7.P11, Y6.1
24MHZ_7: C96.1, U10.N11, Y8.3
24MHZ_8: C95.1, R20.2, U10.P11, Y8.1
24MHZ_9: C125.1, U13.N11, Y10.3
24MHZ_10: C124.1, R26.2, U13.P11, Y10.1
24MHZ_11: C154.1, U16.N11, Y12.3
24MHZ_12: C153.1, R32.2, U16.P11, Y12.1
24MHZ_13: C183.1, U19.N11, Y14.3
24MHZ_14: C182.1, R38.2, U19.P11, Y14.1
24MHZ_15: C212.1, U22.N11, Y16.3
24MHZ_16: C211.1, R44.2, U22.P11, Y16.1
24MHZ_17: C241.1, U25.N11, Y18.3
24MHZ_18: C240.1, R50.2, U25.P11, Y18.1
24MHZ_19: C270.1, U28.N11, Y20.3
24MHZ_20: C269.1, R56.2, U28.P11, Y20.1
24MHZ_21: C299.1, U31.N11, Y22.3
24MHZ_22: C298.1, R62.2, U31.P11, Y22.1
24MHZ_23: C328.1, U34.N11, Y24.3
24MHZ_24: C327.1, R68.2, U34.P11, Y24.1
24MHZ_25: C357.1, U37.N11, Y26.3
24MHZ_26: C356.1, R74.2, U37.P11, Y26.1
24MHZ_27: C386.1, U40.N11, Y28.3
24MHZ_28: C385.1, R80.2, U40.P11, Y28.1
24MHZ_29: C415.1, U43.N11, Y30.3
24MHZ_30: C414.1, R86.2, U43.P11, Y30.1
24MHZ_31: C444.1, U46.N11, Y32.3
24MHZ_32: C443.1, R92.2, U46.P11, Y32.1
32KHZ_1: C8.1, U1.N9, Y1.P$1
32KHZ_2: C9.1, U1.P9, Y1.P$2
32KHZ_3: C36.1, U2.P9, Y3.P$2
32KHZ_4: C35.1, U2.N9, Y3.P$1
32KHZ_5: C65.1, U7.P9, Y5.P$2
32KHZ_6: C64.1, U7.N9, Y5.P$1
32KHZ_7: C94.1, U10.P9, Y7.P$2
32KHZ_8: C93.1, U10.N9, Y7.P$1
32KHZ_9: C123.1, U13.P9, Y9.P$2
32KHZ_10: C122.1, U13.N9, Y9.P$1
32KHZ_11: C152.1, U16.P9, Y11.P$2
32KHZ_12: C151.1, U16.N9, Y11.P$1
32KHZ_13: C181.1, U19.P9, Y13.P$2
32KHZ_14: C180.1, U19.N9, Y13.P$1
32KHZ_15: C210.1, U22.P9, Y15.P$2
32KHZ_16: C209.1, U22.N9, Y15.P$1
32KHZ_17: C239.1, U25.P9, Y17.P$2
32KHZ_18: C238.1, U25.N9, Y17.P$1
32KHZ_19: C268.1, U28.P9, Y19.P$2
32KHZ_20: C267.1, U28.N9, Y19.P$1
32KHZ_21: C297.1, U31.P9, Y21.P$2
32KHZ_22: C296.1, U31.N9, Y21.P$1
32KHZ_23: C326.1, U34.P9, Y23.P$2
32KHZ_24: C325.1, U34.N9, Y23.P$1
32KHZ_25: C355.1, U37.P9, Y25.P$2
32KHZ_26: C354.1, U37.N9, Y25.P$1
32KHZ_27: C384.1, U40.P9, Y27.P$2
32KHZ_28: C383.1, U40.N9, Y27.P$1
32KHZ_29: C413.1, U43.P9, Y29.P$2
32KHZ_30: C412.1, U43.N9, Y29.P$1
32KHZ_31: C442.1, U46.P9, Y31.P$2
32KHZ_32: C441.1, U46.N9, Y31.P$1
32KHZ_TEST: TP1.P$1, U1.M14
32KHZ_TEST1: TP14.P$1, U2.M14
32KHZ_TEST2: TP27.P$1, U7.M14
32KHZ_TEST3: TP40.P$1, U10.M14
32KHZ_TEST4: TP53.P$1, U13.M14
32KHZ_TEST5: TP66.P$1, U16.M14
32KHZ_TEST6: TP79.P$1, U19.M14
32KHZ_TEST7: TP92.P$1, U22.M14
32KHZ_TEST8: TP105.P$1, U25.M14
32KHZ_TEST9: TP118.P$1, U28.M14
32KHZ_TEST10: TP131.P$1, U31.M14
32KHZ_TEST11: TP144.P$1, U34.M14
32KHZ_TEST12: TP157.P$1, U37.M14
32KHZ_TEST13: TP170.P$1, U40.M14
32KHZ_TEST14: TP183.P$1, U43.M14
32KHZ_TEST15: TP196.P$1, U46.M14
34/DAT1: J1.66, U1.K1
34/DAT2: J2.66, U2.K1
34/DAT3: J3.66, U7.K1
34/DAT4: J4.66, U10.K1
34/DAT5: J5.66, U13.K1
34/DAT6: J6.66, U16.K1
34/DAT7: J7.66, U19.K1
34/DAT8: J8.66, U22.K1
34/DAT9: J9.66, U25.K1
34/DAT10: J10.66, U28.K1
34/DAT11: J11.66, U31.K1
34/DAT12: J12.66, U34.K1
34/DAT13: J13.66, U37.K1
34/DAT14: J14.66, U40.K1
34/DAT15: J15.66, U43.K1
34/DAT16: J16.66, U46.K1
35/DAT0: J1.64, U1.J1
35/DAT1: J2.64, U2.J1
35/DAT2: J3.64, U7.J1
35/DAT3: J4.64, U10.J1
35/DAT4: J5.64, U13.J1
35/DAT5: J6.64, U16.J1
35/DAT6: J7.64, U19.J1
35/DAT7: J8.64, U22.J1
35/DAT8: J9.64, U25.J1
35/DAT9: J10.64, U28.J1
35/DAT10: J11.64, U31.J1
35/DAT11: J12.64, U34.J1
35/DAT12: J13.64, U37.J1
35/DAT13: J14.64, U40.J1
35/DAT14: J15.64, U43.J1
35/DAT15: J16.64, U46.J1
36/CLK: J1.60, U1.J3
36/CLK1: J2.60, U2.J3
36/CLK2: J3.60, U7.J3
36/CLK3: J4.60, U10.J3
36/CLK4: J5.60, U13.J3
36/CLK5: J6.60, U16.J3
36/CLK6: J7.60, U19.J3
36/CLK7: J8.60, U22.J3
36/CLK8: J9.60, U25.J3
36/CLK9: J10.60, U28.J3
36/CLK10: J11.60, U31.J3
36/CLK11: J12.60, U34.J3
36/CLK12: J13.60, U37.J3
36/CLK13: J14.60, U40.J3
36/CLK14: J15.60, U43.J3
36/CLK15: J16.60, U46.J3
37/CMD: J1.62, U1.J4
37/CMD1: J2.62, U2.J4
37/CMD2: J3.62, U7.J4
37/CMD3: J4.62, U10.J4
37/CMD4: J5.62, U13.J4
37/CMD5: J6.62, U16.J4
37/CMD6: J7.62, U19.J4
37/CMD7: J8.62, U22.J4
37/CMD8: J9.62, U25.J4
37/CMD9: J10.62, U28.J4
37/CMD10: J11.62, U31.J4
37/CMD11: J12.62, U34.J4
37/CMD12: J13.62, U37.J4
37/CMD13: J14.62, U40.J4
37/CMD14: J15.62, U43.J4
37/CMD15: J16.62, U46.J4
38/DAT1: J2.68, U2.H2
38/DAT2: J1.68, U1.H2
38/DAT3: J3.68, U7.H2
38/DAT4: J4.68, U10.H2
38/DAT5: J5.68, U13.H2
38/DAT6: J6.68, U16.H2
38/DAT7: J7.68, U19.H2
38/DAT8: J8.68, U22.H2
38/DAT9: J9.68, U25.H2
38/DAT10: J10.68, U28.H2
38/DAT11: J11.68, U31.H2
38/DAT12: J12.68, U34.H2
38/DAT13: J13.68, U37.H2
38/DAT14: J14.68, U40.H2
38/DAT15: J15.68, U43.H2
38/DAT16: J16.68, U46.H2
39/DAT1: J2.70, U2.J2
39/DAT2: J3.70, U7.J2
39/DAT3: J1.70, U1.J2
39/DAT4: J4.70, U10.J2
39/DAT5: J5.70, U13.J2
39/DAT6: J6.70, U16.J2
39/DAT7: J7.70, U19.J2
39/DAT8: J8.70, U22.J2
39/DAT9: J9.70, U25.J2
39/DAT10: J10.70, U28.J2
39/DAT11: J11.70, U31.J2
39/DAT12: J12.70, U34.J2
39/DAT13: J13.70, U37.J2
39/DAT14: J14.70, U40.J2
39/DAT15: J15.70, U43.J2
39/DAT16: J16.70, U46.J2
A0/1: J2.34, U2.L11
A0/2: J3.34, U7.L11
A0/3: J4.34, U10.L11
A0/4: J5.34, U13.L11
A0/5: J6.34, U16.L11
A0/6: J7.34, U19.L11
A0/7: J8.34, U22.L11
A0/8: J9.34, U25.L11
A0/9: J10.34, U28.L11
A0/10: J11.34, U31.L11
A0/11: J12.34, U34.L11
A0/12: J13.34, U37.L11
A0/13: J14.34, U40.L11
A0/14: J1.34, U1.L11
A0/15: J15.34, U43.L11
A0/16: J16.34, U46.L11
A1/1: J2.38, U2.M12
A1/2: J3.38, U7.M12
A1/3: J4.38, U10.M12
A1/4: J5.38, U13.M12
A1/5: J6.38, U16.M12
A1/6: J7.38, U19.M12
A1/7: J8.38, U22.M12
A1/8: J9.38, U25.M12
A1/9: J10.38, U28.M12
A1/10: J11.38, U31.M12
A1/11: J12.38, U34.M12
A1/12: J13.38, U37.M12
A1/13: J14.38, U40.M12
A1/14: J15.38, U43.M12
A1/15: J1.38, U1.M12
A1/16: J16.38, U46.M12
AUD_IN/1: J2.54, U2.A11
AUD_IN/2: J3.54, U7.A11
AUD_IN/3: J4.54, U10.A11
AUD_IN/4: J5.54, U13.A11
AUD_IN/5: J6.54, U16.A11
AUD_IN/6: J7.54, U19.A11
AUD_IN/7: J8.54, U22.A11
AUD_IN/8: J1.54, U1.A11
AUD_IN/9: J9.54, U25.A11
AUD_IN/10: J10.54, U28.A11
AUD_IN/11: J11.54, U31.A11
AUD_IN/12: J12.54, U34.A11
AUD_IN/13: J13.54, U37.A11
AUD_IN/14: J14.54, U40.A11
AUD_IN/15: J15.54, U43.A11
AUD_IN/16: J16.54, U46.A11
AUD_OUT/1: J2.56, U2.B11
AUD_OUT/2: J3.56, U7.B11
AUD_OUT/3: J4.56, U10.B11
AUD_OUT/4: J5.56, U13.B11
AUD_OUT/5: J6.56, U16.B11
AUD_OUT/6: J7.56, U19.B11
AUD_OUT/7: J1.56, U1.B11
AUD_OUT/8: J8.56, U22.B11
AUD_OUT/9: J9.56, U25.B11
AUD_OUT/10: J10.56, U28.B11
AUD_OUT/11: J11.56, U31.B11
AUD_OUT/12: J12.56, U34.B11
AUD_OUT/13: J13.56, U37.B11
AUD_OUT/14: J14.56, U40.B11
AUD_OUT/15: J15.56, U43.B11
AUD_OUT/16: J16.56, U46.B11
BATT_VIN/22/A1: J2.49, U2.H13
BATT_VIN/22/A2: J3.49, U7.H13
BATT_VIN/22/A3: J4.49, U10.H13
BATT_VIN/22/A4: J5.49, U13.H13
BATT_VIN/22/A5: J6.49, U16.H13
BATT_VIN/22/A6: J7.49, U19.H13
BATT_VIN/22/A7: J8.49, U22.H13
BATT_VIN/22/A8: J1.49, U1.H13
BATT_VIN/22/A9: J9.49, U25.H13
BATT_VIN/22/A10: J10.49, U28.H13
BATT_VIN/22/A11: J11.49, U31.H13
BATT_VIN/22/A12: J12.49, U34.H13
BATT_VIN/22/A13: J13.49, U37.H13
BATT_VIN/22/A14: J14.49, U40.H13
BATT_VIN/22/A15: J15.49, U43.H13
BATT_VIN/22/A16: J16.49, U46.H13
BCLK/21/A1: J2.50, U2.J13
BCLK/21/A2: J3.50, U7.J13
BCLK/21/A3: J4.50, U10.J13
BCLK/21/A4: J5.50, U13.J13
BCLK/21/A5: J6.50, U16.J13
BCLK/21/A6: J7.50, U19.J13
BCLK/21/A7: J1.50, U1.J13
BCLK/21/A8: J8.50, U22.J13
BCLK/21/A9: J9.50, U25.J13
BCLK/21/A10: J10.50, U28.J13
BCLK/21/A11: J11.50, U31.J13
BCLK/21/A12: J12.50, U34.J13
BCLK/21/A13: J13.50, U37.J13
BCLK/21/A14: J14.50, U40.J13
BCLK/21/A15: J15.50, U43.J13
BCLK/21/A16: J16.50, U46.J13
BOOTMODE0: U1.F11, U3.4
BOOTMODE1: U2.F11, U5.4
BOOTMODE2: U7.F11, U8.4
BOOTMODE3: U10.F11, U11.4
BOOTMODE4: U13.F11, U14.4
BOOTMODE5: U16.F11, U17.4
BOOTMODE6: U19.F11, U20.4
BOOTMODE7: U22.F11, U23.4
BOOTMODE8: U25.F11, U26.4
BOOTMODE9: U28.F11, U29.4
BOOTMODE10: U31.F11, U32.4
BOOTMODE11: U34.F11, U35.4
BOOTMODE12: U37.F11, U38.4
BOOTMODE13: U40.F11, U41.4
BOOTMODE14: U43.F11, U44.4
BOOTMODE15: U46.F11, U47.4
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

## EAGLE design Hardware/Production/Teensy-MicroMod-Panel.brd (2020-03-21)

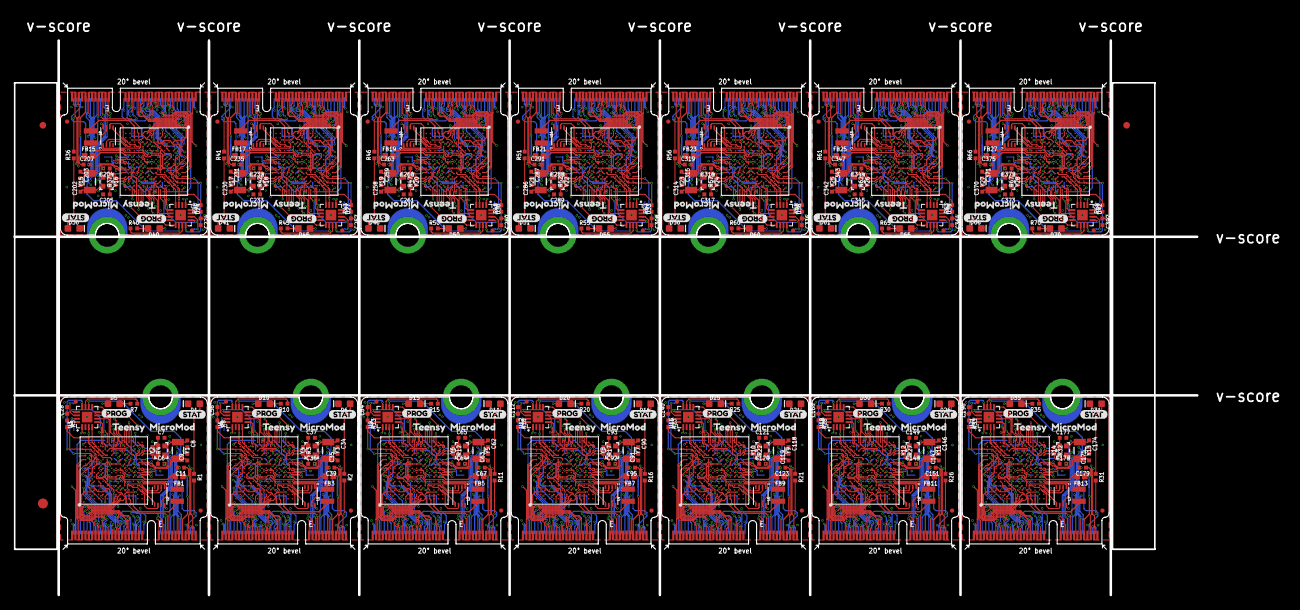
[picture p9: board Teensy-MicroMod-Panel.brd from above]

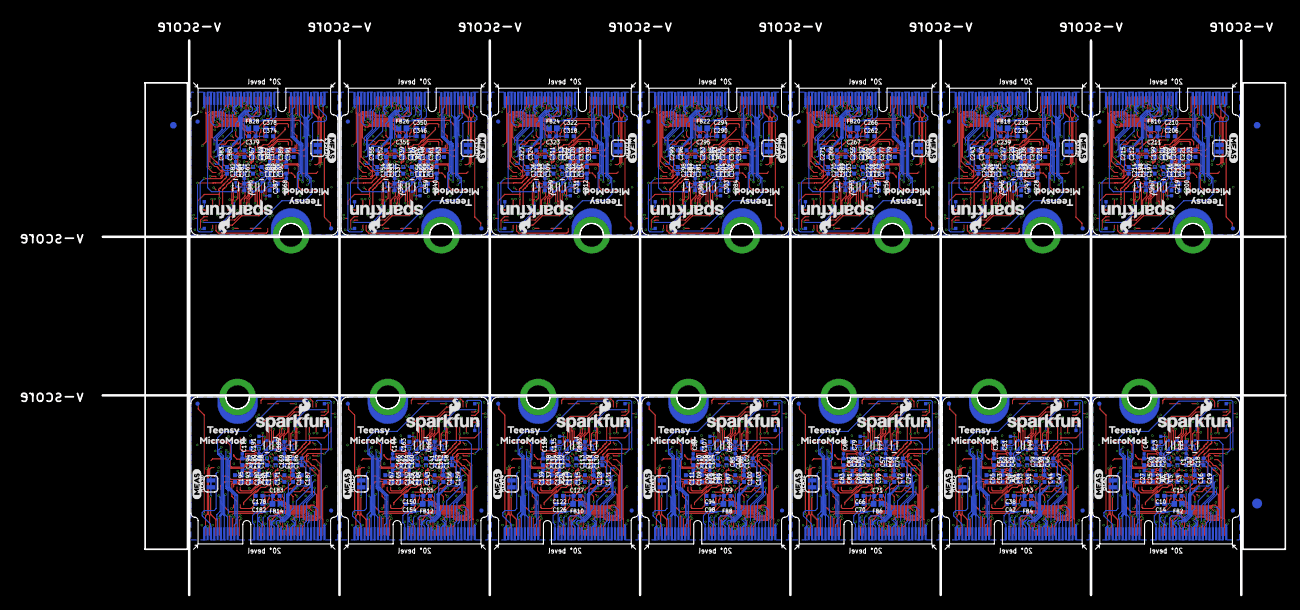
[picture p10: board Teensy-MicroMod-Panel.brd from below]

Board: 4 copper layers, 177.1 x 83.1 mm, 986 parts (619 on the bottom side), 1218 nets.

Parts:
C1, C11, C29, C39, C57, C67, C85, C95, C113, C123, C141, C151, C169, C179, C197, C207, C225, C235, C253, C263, C281, C291, C309, C319, C337, C347, C365, C375: 2.2uF; 0402-TIGHT
C2, C14, C18, C26, C27, C30, C42, C46, C54, C55, C58, C70, C74, C82, C83, C86, C98, C102, C110, C111, C114, C126, C130, C138, C139, C142, C154, C158, C166, C167, C170, C182, C186, C194, C195, C198, C210, C214, C222, C223, C226, C238, C242, C250, C251, C254, C266, C270, C278, C279, C282, C294, C298, C306, C307, C310, C322, C326, C334, C335, C338, C350, C354, C362, C363, C366, C378, C382, C390, C391: 4.7uF; 0402-TIGHT
C3, C4, C12, C13, C15, C17, C20, C22, C23, C24, C25, C28, C31, C32, C40, C41, C43, C45, C48, C50, C51, C52, C53, C56, C59, C60, C68, C69, C71, C73, C76, C78, C79, C80, C81, C84, C87, C88, C96, C97, C99, C101, C104, C106, C107, C108, C109, C112, C115, C116, C124, C125, C127, C129, C132, C134, C135, C136, C137, C140, C143, C144, C152, C153, C155, C157, C160, C162, C163, C164, C165, C168, C171, C172, C180, C181, C183, C185, C188, C190, C191, C192, C193, C196, C199, C200, C208, C209, C211, C213, C216, C218, C219, C220, C221, C224, C227, C228, C236, C237, C239, C241, C244, C246, C247, C248, C249, C252, C255, C256, C264, C265, C267, C269, C272, C274, C275, C276, C277, C280, C283, C284, C292, C293, C295, C297, C300, C302, C303, C304, C305, C308, C311, C312, C320, C321, C323, C325, C328, C330, C331, C332, C333, C336, C339, C340, C348, C349, C351, C353, C356, C358, C359, C360, C361, C364, C367, C368, C376, C377, C379, C381, C384, C386, C387, C388, C389, C392: 0.22uF; 0402-TIGHT
C5, C16, C33, C44, C61, C72, C89, C100, C117, C128, C145, C156, C173, C184, C201, C212, C229, C240, C257, C268, C285, C296, C313, C324, C341, C352, C369, C380: 10nF; 0402-TIGHT
C6, C7, C36, C37, C64, C65, C92, C93, C120, C121, C148, C149, C176, C177, C204, C205, C232, C233, C260, C261, C288, C289, C316, C317, C344, C345, C372, C373: 12pF; 0402-TIGHT
C8, C9, C34, C35, C62, C63, C90, C91, C118, C119, C146, C147, C174, C175, C202, C203, C230, C231, C258, C259, C286, C287, C314, C315, C342, C343, C370, C371: 20pF; 0402-TIGHT
C10, C19, C21, C38, C47, C49, C66, C75, C77, C94, C103, C105, C122, C131, C133, C150, C159, C161, C178, C187, C189, C206, C215, C217, C234, C243, C245, C262, C271, C273, C290, C299, C301, C318, C327, C329, C346, C355, C357, C374, C383, C385: 10uF; 0402-TIGHT
D1, D6, D11, D16, D21, D26, D31, D36, D41, D46, D51, D56, D61, D66: BLUE; LED-0603
D2, D7, D12, D17, D22, D27, D32, D37, D42, D47, D52, D57, D62, D67: 120mA370mV; SOD-523
D3, D4, D8, D9, D13, D14, D18, D19, D23, D24, D28, D29, D33, D34, D38, D39, D43, D44, D48, D49, D53, D54, D58, D59, D63, D64, D68, D69: 120mA/370mV; SOD-523
D5, D10, D15, D20, D25, D30, D35, D40, D45, D50, D55, D60, D65, D70: Yellow; LED-0603
E$1, E$2, E$3, E$4: FIDUCIAL-1X2
E$5, E$6: FIDUCIAL-1.5X3
FB1, FB2, FB3, FB4, FB5, FB6, FB7, FB8, FB9, FB10, FB11, FB12, FB13, FB14, FB15, FB16, FB17, FB18, FB19, FB20, FB21, FB22, FB23, FB24, FB25, FB26, FB27, FB28: 120Ω; 0402
FD1, FD2, FD3, FD4, FD5, FD6, FD7, FD8, FD9, FD10, FD11, FD12, FD13, FD14, FD15, FD16, FD17, FD18, FD19, FD20, FD21, FD22, FD23, FD24, FD25, FD26, FD27, FD28, FD29, FD30, FD31, FD32, FD33, FD34, FD35, FD36, FD37, FD38, FD39, FD40, FD41, FD42, FD43, FD44, FD45, FD46, FD47, FD48, FD49, FD50, FD51, FD52, FD53, FD54, FD55, FD56: FIDUCIALUFIDUCIAL; FIDUCIAL-MICRO
J1, J2, J3, J4, J5, J6, J7, J8, J9, J10, J11, J12, J13, J14: MICROMOD-2222; M.2-CARD-E-22
L1, L2, L3, L4, L5, L6, L7, L8, L9, L10, L11, L12, L13, L14: 4.7μH; 1008(2520)
LOGO1, LOGO2, LOGO3, LOGO4, LOGO5, LOGO6, LOGO7, LOGO8, LOGO9, LOGO10, LOGO11, LOGO12, LOGO13, LOGO14: SFE_LOGO_NAME_FLAME.1_INCH; SFE_LOGO_NAME_FLAME_.1
MEAS, MEAS1, MEAS2, MEAS3, MEAS4, MEAS5, MEAS6, MEAS7, MEAS8, MEAS9, MEAS10, MEAS11, MEAS12, MEAS13: SMT-JUMPER_2_NC_TRACE_SILK
R1, R2, R7, R10, R11, R15, R16, R20, R21, R25, R26, R30, R31, R35, R36, R40, R41, R45, R46, R50, R51, R55, R56, R60, R61, R65, R66, R70: 1k; 0402-TIGHT
R3, R4, R12, R17, R22, R27, R32, R37, R42, R47, R52, R57, R62, R67: 2.2M; 0402-TIGHT
R5, R6, R8, R9, R13, R14, R18, R19, R23, R24, R28, R29, R33, R34, R38, R39, R43, R44, R48, R49, R53, R54, R58, R59, R63, R64, R68, R69: 100k; 0402-TIGHT
TP1, TP2, TP21, TP31, TP41, TP51, TP61, TP71, TP81, TP91, TP101, TP111, TP121, TP131: 32kHz Test; PAD.02X.02
TP3, TP4, TP5, TP6, TP7, TP8, TP9, TP10, TP11, TP12, TP13, TP14, TP15, TP16, TP17, TP18, TP19, TP20, TP22, TP23, TP24, TP25, TP26, TP27, TP28, TP29, TP30, TP32, TP33, TP34, TP35, TP36, TP37, TP38, TP39, TP40, TP42, TP43, TP44, TP45, TP46, TP47, TP48, TP49, TP50, TP52, TP53, TP54, TP55, TP56, TP57, TP58, TP59, TP60, TP62, TP63, TP64, TP65, TP66, TP67, TP68, TP69, TP70, TP72, TP73, TP74, TP75, TP76, TP77, TP78, TP79, TP80, TP82, TP83, TP84, TP85, TP86, TP87, TP88, TP89, TP90, TP92, TP93, TP94, TP95, TP96, TP97, TP98, TP99, TP100, TP102, TP103, TP104, TP105, TP106, TP107, TP108, TP109, TP110, TP112, TP113, TP114, TP115, TP116, TP117, TP118, TP119, TP120, TP122, TP123, TP124, TP125, TP126, TP127, TP128, TP129, TP130, TP132, TP133, TP134, TP135, TP136, TP137, TP138, TP139, TP140: PAD.02X.02
U1, U4, U7, U10, U13, U16, U19, U22, U25, U28, U31, U34, U37, U40: IMXRT1062DV10X10; IMXRT1062
U2, U5, U8, U11, U14, U17, U20, U23, U26, U29, U32, U35, U38, U41: W25QXX; USON-8
U3, U6, U9, U12, U15, U18, U21, U24, U27, U30, U33, U36, U39, U42: MKL02Z32VFG4; QFN-16
U$1, U$3, U$9, U$12, U$16, U$19, U$23, U$26, U$30, U$33, U$37, U$40, U$44, U$47, U$51, U$54, U$58, U$61, U$65, U$68, U$72, U$75, U$79, U$82, U$86, U$89, U$93, U$96: TEENSY2
U$2, U$5, U$8, U$13, U$15, U$20, U$22, U$27, U$29, U$34, U$36, U$41, U$43, U$48, U$50, U$55, U$57, U$62, U$64, U$69, U$71, U$76, U$78, U$83, U$85, U$90, U$92, U$97: MICROMOD0
U$4, U$11, U$18, U$25, U$32, U$39, U$46, U$53, U$60, U$67, U$74, U$81, U$88, U$95: PROG_32
U$6, U$10, U$17, U$24, U$31, U$38, U$45, U$52, U$59, U$66, U$73, U$80, U$87, U$94: STAT_32
U$7, U$14, U$21, U$28, U$35, U$42, U$49, U$56, U$63, U$70, U$77, U$84, U$91, U$98: MEAS_32
Y1, Y3, Y5, Y7, Y9, Y11, Y13, Y15, Y17, Y19, Y21, Y23, Y25, Y27: 32.768kHz; CRYSTAL-SMD-3.2X1.5MM
Y2, Y4, Y6, Y8, Y10, Y12, Y14, Y16, Y18, Y20, Y22, Y24, Y26, Y28: 24MHz; CRYSTAL-SMD-2.0X1.6MM

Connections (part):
3.3V: C1.1, C2.1, C3.1, C4.1, C5.1, C28.1, D2.A, D5.A, FB2.1, J1.2, J1.4, J1.74, R6.1, U1.E6, U1.E9, U1.F5, U1.F10, U1.J6, U1.J10, U1.K4, U1.K5, U1.N14, U1.P12, U2.8, U3.1
3.3V1: C29.1, C30.1, C31.1, C32.1, C33.1, C56.1, D7.A, D10.A, FB4.1, J2.2, J2.4, J2.74, R9.1, U4.E6, U4.E9, U4.F5, U4.F10, U4.J6, U4.J10, U4.K4, U4.K5, U4.N14, U4.P12, U5.8, U6.1
3.3V2: C57.1, C58.1, C59.1, C60.1, C61.1, C84.1, D12.A, D15.A, FB6.1, J3.2, J3.4, J3.74, R14.1, U7.E6, U7.E9, U7.F5, U7.F10, U7.J6, U7.J10, U7.K4, U7.K5, U7.N14, U7.P12, U8.8, U9.1
3.3V3: C85.1, C86.1, C87.1, C88.1, C89.1, C112.1, D17.A, D20.A, FB8.1, J4.2, J4.4, J4.74, R19.1, U10.E6, U10.E9, U10.F5, U10.F10, U10.J6, U10.J10, U10.K4, U10.K5, U10.N14, U10.P12, U11.8, U12.1
3.3V4: C113.1, C114.1, C115.1, C116.1, C117.1, C140.1, D22.A, D25.A, FB10.1, J5.2, J5.4, J5.74, R24.1, U13.E6, U13.E9, U13.F5, U13.F10, U13.J6, U13.J10, U13.K4, U13.K5, U13.N14, U13.P12, U14.8, U15.1
3.3V5: C141.1, C142.1, C143.1, C144.1, C145.1, C168.1, D27.A, D30.A, FB12.1, J6.2, J6.4, J6.74, R29.1, U16.E6, U16.E9, U16.F5, U16.F10, U16.J6, U16.J10, U16.K4, U16.K5, U16.N14, U16.P12, U17.8, U18.1
3.3V6: C169.1, C170.1, C171.1, C172.1, C173.1, C196.1, D32.A, D35.A, FB14.1, J7.2, J7.4, J7.74, R34.1, U19.E6, U19.E9, U19.F5, U19.F10, U19.J6, U19.J10, U19.K4, U19.K5, U19.N14, U19.P12, U20.8, U21.1
3.3V7: C197.1, C198.1, C199.1, C200.1, C201.1, C224.1, D37.A, D40.A, FB16.1, J8.2, J8.4, J8.74, R39.1, U22.E6, U22.E9, U22.F5, U22.F10, U22.J6, U22.J10, U22.K4, U22.K5, U22.N14, U22.P12, U23.8, U24.1
3.3V8: C225.1, C226.1, C227.1, C228.1, C229.1, C252.1, D42.A, D45.A, FB18.1, J9.2, J9.4, J9.74, R44.1, U25.E6, U25.E9, U25.F5, U25.F10, U25.J6, U25.J10, U25.K4, U25.K5, U25.N14, U25.P12, U26.8, U27.1
3.3V9: C253.1, C254.1, C255.1, C256.1, C257.1, C280.1, D47.A, D50.A, FB20.1, J10.2, J10.4, J10.74, R49.1, U28.E6, U28.E9, U28.F5, U28.F10, U28.J6, U28.J10, U28.K4, U28.K5, U28.N14, U28.P12, U29.8, U30.1
3.3V10: C281.1, C282.1, C283.1, C284.1, C285.1, C308.1, D52.A, D55.A, FB22.1, J11.2, J11.4, J11.74, R54.1, U31.E6, U31.E9, U31.F5, U31.F10, U31.J6, U31.J10, U31.K4, U31.K5, U31.N14, U31.P12, U32.8, U33.1
3.3V11: C309.1, C310.1, C311.1, C312.1, C313.1, C336.1, D57.A, D60.A, FB24.1, J12.2, J12.4, J12.74, R59.1, U34.E6, U34.E9, U34.F5, U34.F10, U34.J6, U34.J10, U34.K4, U34.K5, U34.N14, U34.P12, U35.8, U36.1
3.3V12: C337.1, C338.1, C339.1, C340.1, C341.1, C364.1, D62.A, D65.A, FB26.1, J13.2, J13.4, J13.74, R64.1, U37.E6, U37.E9, U37.F5, U37.F10, U37.J6, U37.J10, U37.K4, U37.K5, U37.N14, U37.P12, U38.8, U39.1
3.3V13: C365.1, C366.1, C367.1, C368.1, C369.1, C392.1, D67.A, D70.A, FB28.1, J14.2, J14.4, J14.74, R69.1, U40.E6, U40.E9, U40.F5, U40.F10, U40.J6, U40.J10, U40.K4, U40.K5, U40.N14, U40.P12, U41.8, U42.1
34/DAT1: J1.66, U1.K1
34/DAT2: J2.66, U4.K1
34/DAT3: J3.66, U7.K1
34/DAT4: J4.66, U10.K1
34/DAT5: J5.66, U13.K1
34/DAT6: J6.66, U16.K1
34/DAT7: J7.66, U19.K1
34/DAT8: J8.66, U22.K1
34/DAT9: J9.66, U25.K1
34/DAT10: J10.66, U28.K1
34/DAT11: J11.66, U31.K1
34/DAT12: J12.66, U34.K1
34/DAT13: J13.66, U37.K1
34/DAT14: J14.66, U40.K1
35/DAT0: J1.64, U1.J1
35/DAT1: J2.64, U4.J1
35/DAT2: J3.64, U7.J1
35/DAT3: J4.64, U10.J1
35/DAT4: J5.64, U13.J1
35/DAT5: J6.64, U16.J1
35/DAT6: J7.64, U19.J1
35/DAT7: J8.64, U22.J1
35/DAT8: J9.64, U25.J1
35/DAT9: J10.64, U28.J1
35/DAT10: J11.64, U31.J1
35/DAT11: J12.64, U34.J1
35/DAT12: J13.64, U37.J1
35/DAT13: J14.64, U40.J1
36/CLK: J1.60, U1.J3
36/CLK1: J2.60, U4.J3
36/CLK2: J3.60, U7.J3
36/CLK3: J4.60, U10.J3
36/CLK4: J5.60, U13.J3
36/CLK5: J6.60, U16.J3
36/CLK6: J7.60, U19.J3
36/CLK7: J8.60, U22.J3
36/CLK8: J9.60, U25.J3
36/CLK9: J10.60, U28.J3
36/CLK10: J11.60, U31.J3
36/CLK11: J12.60, U34.J3
36/CLK12: J13.60, U37.J3
36/CLK13: J14.60, U40.J3
37/CMD: J1.62, U1.J4
37/CMD1: J2.62, U4.J4
37/CMD2: J3.62, U7.J4
37/CMD3: J4.62, U10.J4
37/CMD4: J5.62, U13.J4
37/CMD5: J6.62, U16.J4
37/CMD6: J7.62, U19.J4
37/CMD7: J8.62, U22.J4
37/CMD8: J9.62, U25.J4
37/CMD9: J10.62, U28.J4
37/CMD10: J11.62, U31.J4
37/CMD11: J12.62, U34.J4
37/CMD12: J13.62, U37.J4
37/CMD13: J14.62, U40.J4
38/DAT1: J2.70, U4.H2
38/DAT2: J3.70, U7.H2
38/DAT3: J1.70, U1.H2
38/DAT4: J4.70, U10.H2
38/DAT5: J5.70, U13.H2
38/DAT6: J6.70, U16.H2
38/DAT7: J7.70, U19.H2
38/DAT8: J8.70, U22.H2
38/DAT9: J9.70, U25.H2
38/DAT10: J10.70, U28.H2
38/DAT11: J11.70, U31.H2
38/DAT12: J12.70, U34.H2
38/DAT13: J13.70, U37.H2
38/DAT14: J14.70, U40.H2
39/DAT1: J2.68, U4.J2
39/DAT2: J1.68, U1.J2
39/DAT3: J3.68, U7.J2
39/DAT4: J4.68, U10.J2
39/DAT5: J5.68, U13.J2
39/DAT6: J6.68, U16.J2
39/DAT7: J7.68, U19.J2
39/DAT8: J8.68, U22.J2
39/DAT9: J9.68, U25.J2
39/DAT10: J10.68, U28.J2
39/DAT11: J11.68, U31.J2
39/DAT12: J12.68, U34.J2
39/DAT13: J13.68, U37.J2
39/DAT14: J14.68, U40.J2
ADC1ST/14/A0: J1.34, U1.L11
ADC1ST/14/A1: J2.34, U4.L11
ADC1ST/14/A2: J3.34, U7.L11
ADC1ST/14/A3: J4.34, U10.L11
ADC1ST/14/A4: J5.34, U13.L11
ADC1ST/14/A5: J6.34, U16.L11
ADC1ST/14/A6: J7.34, U19.L11
ADC1ST/14/A7: J8.34, U22.L11
ADC1ST/14/A8: J9.34, U25.L11
ADC1ST/14/A9: J10.34, U28.L11
ADC1ST/14/A10: J11.34, U31.L11
ADC1ST/14/A11: J12.34, U34.L11
ADC1ST/14/A12: J13.34, U37.L11
ADC1ST/14/A13: J14.34, U40.L11
ADC2ND/15/A1: J1.38, U1.M12
ADC2ND/15/A2: J2.38, U4.M12
ADC2ND/15/A3: J3.38, U7.M12
ADC2ND/15/A4: J4.38, U10.M12
ADC2ND/15/A5: J5.38, U13.M12
ADC2ND/15/A6: J6.38, U16.M12
ADC2ND/15/A7: J7.38, U19.M12
ADC2ND/15/A8: J8.38, U22.M12
ADC2ND/15/A9: J9.38, U25.M12
ADC2ND/15/A10: J10.38, U28.M12
ADC2ND/15/A11: J11.38, U31.M12
ADC2ND/15/A12: J12.38, U34.M12
ADC2ND/15/A13: J13.38, U37.M12
ADC2ND/15/A14: J14.38, U40.M12
AUD_IN/1: J2.54, U4.A11
AUD_IN/2: J3.54, U7.A11
AUD_IN/3: J4.54, U10.A11
AUD_IN/4: J5.54, U13.A11
AUD_IN/5: J6.54, U16.A11
AUD_IN/6: J7.54, U19.A11
AUD_IN/7: J8.54, U22.A11
AUD_IN/8: J1.54, U1.A11
AUD_IN/9: J9.54, U25.A11
AUD_IN/10: J10.54, U28.A11
AUD_IN/11: J11.54, U31.A11
AUD_IN/12: J12.54, U34.A11
AUD_IN/13: J13.54, U37.A11
AUD_IN/14: J14.54, U40.A11
AUD_OUT/1: J2.56, U4.B11
AUD_OUT/2: J3.56, U7.B11
AUD_OUT/3: J4.56, U10.B11
AUD_OUT/4: J5.56, U13.B11
AUD_OUT/5: J6.56, U16.B11
AUD_OUT/6: J7.56, U19.B11
AUD_OUT/7: J1.56, U1.B11
AUD_OUT/8: J8.56, U22.B11
AUD_OUT/9: J9.56, U25.B11
AUD_OUT/10: J10.56, U28.B11
AUD_OUT/11: J11.56, U31.B11
AUD_OUT/12: J12.56, U34.B11
AUD_OUT/13: J13.56, U37.B11
AUD_OUT/14: J14.56, U40.B11
BATT_VIN/22/A1: J2.51, U4.H13
BATT_VIN/22/A2: J3.51, U7.H13
BATT_VIN/22/A3: J4.51, U10.H13
BATT_VIN/22/A4: J5.51, U13.H13
BATT_VIN/22/A5: J6.51, U16.H13
BATT_VIN/22/A6: J7.51, U19.H13
BATT_VIN/22/A7: J8.51, U22.H13
BATT_VIN/22/A8: J1.51, U1.H13
BATT_VIN/22/A9: J9.51, U25.H13
BATT_VIN/22/A10: J10.51, U28.H13
BATT_VIN/22/A11: J11.51, U31.H13
BATT_VIN/22/A12: J12.51, U34.H13
BATT_VIN/22/A13: J13.51, U37.H13
BATT_VIN/22/A14: J14.51, U40.H13
BCLK/21/A1: J2.50, U4.J13
BCLK/21/A2: J3.50, U7.J13
BCLK/21/A3: J4.50, U10.J13
BCLK/21/A4: J5.50, U13.J13
BCLK/21/A5: J6.50, U16.J13
BCLK/21/A6: J7.50, U19.J13
BCLK/21/A7: J1.50, U1.J13
BCLK/21/A8: J8.50, U22.J13
BCLK/21/A9: J9.50, U25.J13
BCLK/21/A10: J10.50, U28.J13
BCLK/21/A11: J11.50, U31.J13
BCLK/21/A12: J12.50, U34.J13
BCLK/21/A13: J13.50, U37.J13
BCLK/21/A14: J14.50, U40.J13
BOOTMODE0: U1.F11, U3.4
BOOTMODE1: U4.F11, U6.4
BOOTMODE2: U7.F11, U9.4
BOOTMODE3: U10.F11, U12.4
BOOTMODE4: U13.F11, U15.4
BOOTMODE5: U16.F11, U18.4
BOOTMODE6: U19.F11, U21.4
BOOTMODE7: U22.F11, U24.4
BOOTMODE8: U25.F11, U27.4
BOOTMODE9: U28.F11, U30.4
BOOTMODE10: U31.F11, U33.4
BOOTMODE11: U34.F11, U36.4
BOOTMODE12: U37.F11, U39.4
BOOTMODE13: U40.F11, U42.4
CAN_RX/1: J2.41, U4.E4
CAN_RX/2: J3.41, U7.E4
CAN_RX/3: J4.41, U10.E4
CAN_RX/4: J5.41, U13.E4
CAN_RX/5: J6.41, U16.E4
CAN_RX/6: J7.41, U19.E4
CAN_RX/7: J8.41, U22.E4
CAN_RX/8: J9.41, U25.E4
CAN_RX/9: J10.41, U28.E4
CAN_RX/10: J11.41, U31.E4
CAN_RX/11: J12.41, U34.E4
CAN_RX/12: J13.41, U37.E4
CAN_RX/13: J14.41, U40.E4
CAN_RX/30: J1.41, U1.E4
CAN_TX/1: J2.43, U4.C3
CAN_TX/2: J3.43, U7.C3
CAN_TX/3: J4.43, U10.C3
CAN_TX/4: J5.43, U13.C3
CAN_TX/5: J6.43, U16.C3
CAN_TX/6: J7.43, U19.C3
CAN_TX/7: J8.43, U22.C3
CAN_TX/8: J9.43, U25.C3
CAN_TX/9: J10.43, U28.C3
CAN_TX/10: J11.43, U31.C3
CAN_TX/11: J12.43, U34.C3
CAN_TX/12: J13.43, U37.C3
CAN_TX/13: J14.43, U40.C3
CAN_TX/31: J1.43, U1.C3
CS/1: J2.49, U4.D7
CS/2: J3.49, U7.D7
CS/3: J4.49, U10.D7
CS/4: J5.49, U13.D7
CS/5: J6.49, U16.D7
CS/6: J7.49, U19.D7
CS/7: J8.49, U22.D7
CS/8: J9.49, U25.D7
CS/9: J10.49, U28.D7
CS/10: J1.49, U1.D7
CS/11: J11.49, U31.D7
CS/12: J12.49, U34.D7
CS/13: J13.49, U37.D7
CS/14: J14.49, U40.D7
DEBUG_EN: U1.F3, U3.15
DEBUG_EN1: U4.F3, U6.15
DEBUG_EN2: U7.F3, U9.15
DEBUG_EN3: U10.F3, U12.15
DEBUG_EN4: U13.F3, U15.15
DEBUG_EN5: U16.F3, U18.15
DEBUG_EN6: U19.F3, U21.15
DEBUG_EN7: U22.F3, U24.15
DEBUG_EN8: U25.F3, U27.15
DEBUG_EN9: U28.F3, U30.15
DEBUG_EN10: U31.F3, U33.15
DEBUG_EN11: U34.F3, U36.15
DEBUG_EN12: U37.F3, U39.15
DEBUG_EN13: U40.F3, U42.15
DEBUG_SWO: U1.D10, U3.12
DEBUG_SWO1: U4.D10, U6.12
DEBUG_SWO2: U7.D10, U9.12
DEBUG_SWO3: U10.D10, U12.12
DEBUG_SWO4: U13.D10, U15.12
DEBUG_SWO5: U16.D10, U18.12
DEBUG_SWO6: U19.D10, U21.12
DEBUG_SWO7: U22.D10, U24.12
DEBUG_SWO8: U25.D10, U27.12
DEBUG_SWO9: U28.D10, U30.12
DEBUG_SWO10: U31.D10, U33.12
DEBUG_SWO11: U34.D10, U36.12
DEBUG_SWO12: U37.D10, U39.12
DEBUG_SWO13: U40.D10, U42.12
GND: C1.2, C2.2, C3.2, C4.2, C5.2, C6.2, C7.2, C8.2, C9.2, C10.2, C11.2, C12.2, C13.2, C14.2, C15.2, C16.2, C17.2, C18.2, C19.2, C20.2, C21.2, C22.2, C23.2, C24.2, C25.2, C26.2, C27.2, C28.2, D1.C, J1.1, J1.7, J1.33, J1.36, J1.39, J1.45, J1.75, J1.GND, J1.GND-SM-B, R4.1, R5.1, U1.A1, U1.A14, U1.B5, U1.B10, U1.E2, U1.E13, U1.G7, U1.G8, U1.G14, U1.H7, U1.H8, U1.J7, U1.J8, U1.K2, U1.K6, U1.K9, U1.K13, U1.L9, U1.N1, U1.N2, U1.N5, U1.N8, U1.P1, U1.P14, U2.4, U3.2, U3.17
GND1: C29.2, C30.2, C31.2, C32.2, C33.2, C34.2, C35.2, C36.2, C37.2, C38.2, C39.2, C40.2, C41.2, C42.2, C43.2, C44.2, C45.2, C46.2, C47.2, C48.2, C49.2, C50.2, C51.2, C52.2, C53.2, C54.2, C55.2, C56.2, D6.C, J2.1, J2.7, J2.33, J2.36, J2.39, J2.45, J2.75, J2.GND, J2.GND-SM-B, R3.1, R8.1, U4.A1, U4.A14, U4.B5, U4.B10, U4.E2, U4.E13, U4.G7, U4.G8, U4.G14, U4.H7, U4.H8, U4.J7, U4.J8, U4.K2, U4.K6, U4.K9, U4.K13, U4.L9, U4.N1, U4.N2, U4.N5, U4.N8, U4.P1, U4.P14, U5.4, U6.2, U6.17
GND2: C57.2, C58.2, C59.2, C60.2, C61.2, C62.2, C63.2, C64.2, C65.2, C66.2, C67.2, C68.2, C69.2, C70.2, C71.2, C72.2, C73.2, C74.2, C75.2, C76.2, C77.2, C78.2, C79.2, C80.2, C81.2, C82.2, C83.2, C84.2, D11.C, J3.1, J3.7, J3.33, J3.36, J3.39, J3.45, J3.75, J3.GND, J3.GND-SM-B, R12.1, R13.1, U7.A1, U7.A14, U7.B5, U7.B10, U7.E2, U7.E13, U7.G7, U7.G8, U7.G14, U7.H7, U7.H8, U7.J7, U7.J8, U7.K2, U7.K6, U7.K9, U7.K13, U7.L9, U7.N1, U7.N2, U7.N5, U7.N8, U7.P1, U7.P14, U8.4, U9.2, U9.17
GND3: C85.2, C86.2, C87.2, C88.2, C89.2, C90.2, C91.2, C92.2, C93.2, C94.2, C95.2, C96.2, C97.2, C98.2, C99.2, C100.2, C101.2, C102.2, C103.2, C104.2, C105.2, C106.2, C107.2, C108.2, C109.2, C110.2, C111.2, C112.2, D16.C, J4.1, J4.7, J4.33, J4.36, J4.39, J4.45, J4.75, J4.GND, J4.GND-SM-B, R17.1, R18.1, U10.A1, U10.A14, U10.B5, U10.B10, U10.E2, U10.E13, U10.G7, U10.G8, U10.G14, U10.H7, U10.H8, U10.J7, U10.J8, U10.K2, U10.K6, U10.K9, U10.K13, U10.L9, U10.N1, U10.N2, U10.N5, U10.N8, U10.P1, U10.P14, U11.4, U12.2, U12.17
GND4: C113.2, C114.2, C115.2, C116.2, C117.2, C118.2, C119.2, C120.2, C121.2, C122.2, C123.2, C124.2, C125.2, C126.2, C127.2, C128.2, C129.2, C130.2, C131.2, C132.2, C133.2, C134.2, C135.2, C136.2, C137.2, C138.2, C139.2, C140.2, D21.C, J5.1, J5.7, J5.33, J5.36, J5.39, J5.45, J5.75, J5.GND, J5.GND-SM-B, R22.1, R23.1, U13.A1, U13.A14, U13.B5, U13.B10, U13.E2, U13.E13, U13.G7, U13.G8, U13.G14, U13.H7, U13.H8, U13.J7, U13.J8, U13.K2, U13.K6, U13.K9, U13.K13, U13.L9, U13.N1, U13.N2, U13.N5, U13.N8, U13.P1, U13.P14, U14.4, U15.2, U15.17
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

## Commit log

2020-03-21 Add production files
    [Teensy-MicroMod-Panel.GBL, Teensy-MicroMod-Panel.GBO, Teensy-MicroMod-Panel.GBP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]
2020-03-21 Add docs. Add lib.
    [bga_pinout_t41.ods]
2020-03-21 v11 PCB. Fix connection to DCDC_SENSE.
    [MicroMod-Teensy.brd, MicroMod-Teensy.sch]
2020-03-23 Routed with 5mil. Increased clk spacing.
    [MicroMod-Teensy-Panel.GBL, MicroMod-Teensy-Panel.GBO, MicroMod-Teensy-Panel.GBP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]
2020-03-24 Breakout PMIC. Reduce beads to 0402T.
    [MicroMod-Teensy-Panel.GBL, MicroMod-Teensy-Panel.GBO, MicroMod-Teensy-Panel.GBP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]
2020-03-24 Rearrange UART pins
    [MicroMod-Teensy.brd, MicroMod-Teensy.sch]
2020-03-27 Add power control circuitry.
    [MicroMod-Teensy.brd, MicroMod-Teensy.sch]
2020-03-27 Adding panel files
    [MicroMod-Teensy-Panel.GBL, MicroMod-Teensy-Panel.GBO, MicroMod-Teensy-Panel.GBP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]
2020-03-27 Remove cream from test points
    [MicroMod-Teensy-Panel.GBL, MicroMod-Teensy-Panel.GBO, MicroMod-Teensy-Panel.GBP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]
2020-04-01 Matches trace lenths to flash. New panel.
    [MicroMod-Teensy-Panel.GBL, MicroMod-Teensy-Panel.GBO, MicroMod-Teensy-Panel.GBP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]
2020-04-04 Route bus pins to v11.
    [MicroMod-Teensy-Panel.brd, MicroMod-Teensy.brd, MicroMod-Teensy.sch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]
2020-04-14 Add ordering instructions
    [MicroMod-Teensy.brd, MicroMod-Teensy.sch]
2020-04-14 Update Micromod connector to current version
    [MicroMod-Teensy.brd, MicroMod-Teensy.sch]
2020-04-15 Adding test point measurements
    [MicroMod-Teensy.brd, MicroMod-Teensy.sch]
2020-05-14 Add 3.3V EN. Increase flash IC size to 6x5mm.
    [MicroMod-Teensy.brd, MicroMod-Teensy.sch]
2020-05-14 Move a few vias from BGA pads.
    [MicroMod-Teensy.brd]
2020-05-14 Move via away from BGA
    [MicroMod-Teensy.brd]
2020-05-14 Move via away from ball.
    [MicroMod-Teensy.brd]
2020-05-18 Reroute 3.3V_EN to available standard GPIO 28. Adjust R4 for more space.
    [MicroMod-Teensy.brd, MicroMod-Teensy.sch]
2020-05-19 Adjust inductor position. Change MM logo.
    [MicroMod-Teensy.brd, MicroMod-Teensy.sch]
2020-05-19 v12 production files
    [MicroMod-Teensy-Panel.GBL, MicroMod-Teensy-Panel.GBO, MicroMod-Teensy-Panel.GBP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]
2020-06-09 Add PROD_IDs to 120ohm ferrite
    [MicroMod-Teensy.brd, MicroMod-Teensy.sch]
2020-06-19 Fix DAT2/DAT3, now correctly connected to B0_04 and B0_05.
    [MicroMod-Teensy.brd, MicroMod-Teensy.sch]
2020-06-19 Fix incorrect SDA/SCL1 board edge connector pinout
    [MicroMod-Teensy.brd, MicroMod-Teensy.sch]
2020-06-23 Update copper to v13. Add production files.
    [MicroMod-Teensy-Panel.GBL, MicroMod-Teensy-Panel.GBO, MicroMod-Teensy-Panel.GBP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]
2020-08-21 Remove traces from beneath xtals.
    [MicroMod-Teensy.brd]
2020-08-24 Switch layers 2/15 to put ground under xtals. Increase GND plane on layer 15.
    [MicroMod-Teensy.brd, MicroMod-Teensy.sch]
2020-08-24 Increase TP size and relocate to more open areas
    [MicroMod-Teensy.brd, MicroMod-Teensy.sch]
2020-08-24 High freq trace length matching
    [MicroMod-Teensy.brd]
2020-08-24 Opening layer 2 for better GND connections
    [MicroMod-Teensy.brd, MicroMod-Teensy.sch]
2020-08-25 Moved test-points for ideal testing
    [MicroMod-Teensy.brd]
2020-08-25 Connect 3.3V_Controlled to peripherals. Increase internal power trace widths.
    [MicroMod-Teensy.brd, MicroMod-Teensy.sch]
2020-08-26 moved some TP's around to get clearence for pogopins
    [MicroMod-Teensy.brd, MicroMod-Teensy.sch]
2020-08-26 Production v14 panel and gerber files
    [MicroMod-Teensy-Panel.GBL, MicroMod-Teensy-Panel.GBO, MicroMod-Teensy-Panel.GBP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]
2020-08-26 Incorporate TP changes
    [MicroMod-Teensy-Panel.GBL, MicroMod-Teensy-Panel.GBS]
2020-08-27 DFM changes: move traces to avoid t/b stop exposure
    [MicroMod-Teensy.brd]
2020-08-28 Adding production panel files
    [MicroMod-Teensy.brd, MicroMod-Teensy.sch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]
2020-08-29 Move trace away from top edge
    [MicroMod-Teensy.brd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]
2020-08-31 Move trace away from edge to pass DFM requirements
    [MicroMod-Teensy.brd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]
2020-10-01 Update SPI0 net names.
    [MicroMod-Teensy.brd, MicroMod-Teensy.sch]
2020-10-19 Add designed by text on PCB
    [MicroMod-Teensy.brd]
2021-04-19 Add ENIG finish note.
    [MicroMod-Teensy.brd]
2021-04-19 Add panel files for v15 with ENIG finish notes
    [MicroMod-Teensy-Panel.GBL, MicroMod-Teensy-Panel.GBO, MicroMod-Teensy-Panel.GBP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]
2021-04-19 Re-add v15 panel files
    [MicroMod-Teensy-Panel.GBL, MicroMod-Teensy-Panel.GBO, MicroMod-Teensy-Panel.GBP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]
2021-09-21 Adding lockable version of PCB
    [MicroMod-Teensy-Lockable-Panel.GBL, MicroMod-Teensy-Lockable-Panel.GBO, MicroMod-Teensy-Lockable-Panel.GBP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]
2021-11-03 Correct swapped pin numbers on DAT2/3.
    This stems from an error in the original Teensy 4.0 schematic. It was found and corrected but Paul swapped the pin numbers where we swapped the net names. This should get us back on the same page.
    [MicroMod-Teensy.brd, MicroMod-Teensy.sch]

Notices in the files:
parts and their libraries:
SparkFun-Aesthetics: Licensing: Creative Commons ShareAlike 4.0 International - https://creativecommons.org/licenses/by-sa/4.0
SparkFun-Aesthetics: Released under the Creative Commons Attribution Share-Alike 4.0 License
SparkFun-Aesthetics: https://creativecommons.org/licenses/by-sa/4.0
